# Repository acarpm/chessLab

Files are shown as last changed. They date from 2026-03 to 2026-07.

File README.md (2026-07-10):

# ChessLab — Documentation technique

Échiquier connecté détectant la position des pièces (capteurs à effet Hall) et affichant un retour visuel case par case (LEDs RGB adressables), pour visualiser une partie et aider à l'apprentissage du jeu.

## Architecture système

```
                        ESP32-C6
        WiFi 6 · BLE 5 · RISC-V 160 MHz · 512 KB SRAM
                            |
        +-------------------+-------------------+
        |                   |                   |
  Capteurs Hall         LEDs RGB           Alimentation
   (8x8 = 64)          (8x8 = 64)          Pack 18650
```

## Hardware

### Capteurs de position — SS49E

Capteur à effet Hall Analogique, suffisant pour détecter la présence ou l'absence d'une pièce sur une case. 

### LEDs — WS2812B (NeoPixel)

64 LEDs adressables individuellement, câblées en une seule chaîne série (une ligne de données, montage serpentin case par case). Alimentation 5 V, consommation crête d'environ 60 mA par LED.

### Multiplexage des capteurs Hall

64 capteurs analogiques dépassent le nombre de broches disponibles sur l'ESP32-C6. Solution retenue : multiplexeurs analogiques 74HC4051 (8 voies vers 1), soit 8 multiplexeurs pour 64 capteurs, ramenant le besoin à environ 11 broches ESP32.

### Alimentation — 18650

- 2 cellules 18650 montées en parallèle (~6000 mAh)
- Gestion de charge : IC TP4056
- Régulation :
  - 5 V / 3 A pour les LEDs WS2812B (convertisseur buck MP3608)
  - 3,3 V pour l'ESP32 et les capteurs Hall (LDO AMS1117-3.3)

## Circuit d'alimentation (mise sous tension)

Commutation assurée par un MOSFET P-Channel AO3401, piloté par le bouton d'alimentation et maintenu par l'ESP32 :

```
VBAT
 |
 R1 10k
 |
 +----------------------> Gate AO3401 (P-MOS)
 |                              |
 |        +---- R2 100k --------+
 |        |
 |     Source AO3401 = VBAT
 |        |
 |       Drain --------------------> VSYS
 |                                     |
BTN_PWR                          (MT3608 + AMS1117)
 |                                     |
 +---- vers Gate                 ESP32-C6
                                   |         |
                          GPIO_PWR_HOLD  GPIO_BTN_PWR
                          (maintien ON)  (lecture bouton)
```

**Séquence d'allumage**
1. Appui sur BTN_PWR
2. La gate du MOSFET passe à GND, le MOSFET conduit
3. VSYS s'active, l'ESP32 démarre
4. L'ESP32 maintient son GPIO à l'état bas pour garder le MOSFET conducteur
5. Le bouton peut être relâché, le système reste alimenté

**Extinction logicielle**
1. Inactivité détectée (par exemple 10 minutes sans coup joué)
2. Sauvegarde de l'état de la partie si nécessaire
3. Le GPIO passe à l'état haut, le MOSFET se bloque et coupe l'alimentation

**Extinction manuelle**
1. Appui long sur BTN_PWR (environ 3 secondes)
2. Détection par l'ESP32 via le GPIO de lecture du bouton
3. Même séquence que l'extinction logicielle

## Répartition des composants entre les deux cartes

| Carte principale | Carte d'alimentation |
|---|---|
| ESP32-C6 | TP4056 |
| Connecteur USB-C | DW01A + FS8205A |
| 64× WS2812B | Connecteur 18650 |
| 64× SS49E | MT3608 (5 V) |
| 8× 74HC4051 | AMS1117 (3,3 V) |
| 1× 74HC138 | Commutation MOSFET |
| BTN_BOOT + BTN_RESET | BTN_PWR + LED power |
| Connecteur JST vers carte d'alimentation | Connecteur JST vers carte principale |

Les deux cartes sont reliées par un connecteur JST 4 broches :

| Broche | Signal |
|---|---|
| 1 | VBAT (18650+) |
| 2 | GND |
| 3 | 5 V (sortie MT3608 vers carte principale) |
| 4 | 3,3 V (sortie AMS1117 vers carte principale) |

## Layout PCB

- Routage serpentin des WS2812B (entrée/sortie de données case par case)
- Matrices de capteurs Hall organisées en lignes/colonnes vers les multiplexeurs
- Épaisseur de PCB standard : 1,6 mm
- Couche diffusante imprimée en 3D au-dessus des LEDs

### Largeurs de piste

| Signal | Largeur |
|---|---|
| Données / GPIO | 0,25 mm |
| Alimentation 3,3 V | 0,5 mm |
| Alimentation 5 V (LEDs) | 1,0 mm |
| VBAT | 1,0 mm |
| VSYS | 1,0 mm |
| USB D+ / D- | 0,2 mm |

### Vias

| Type | Perçage | Pad |
|---|---|---|
| Standard | 0,4 mm | 0,8 mm |
| Puissance | 0,6 mm | 1,2 mm |

## Pinout ESP32-C6

| Broche | GPIO | Fonction |
|---|---|---|
| 13 | GPIO12 | USB D- |
| 14 | GPIO13 | USB D+ |
| 8 | GPIO0 | Mux — sélection canal S0 |
| 9 | GPIO1 | Mux — sélection canal S1 |
| 27 | GPIO2 | Mux — sélection canal S2 |
| 16 | GPIO18 | 74HC138 — sélection rangée A0 |
| 25 | GPIO16 | 74HC138 — sélection rangée A1 |
| 24 | GPIO17 | 74HC138 — sélection rangée A2 |
| 26 | GPIO3 | Lecture capteurs Hall (A_OUT) |
| 17 | GPIO19 | Données WS2812B (via résistance 33 Ω) |
| 18 | GPIO20 | VBAT |
| 15 | GPIO9 | Bouton BOOT |
| 19 | GPIO21 | Lecture bouton d'alimentation (BTN_PWR) |
| 20 | GPIO22 | Maintien alimentation (PWR_HOLD) |

## Fixation des pièces

Aimants cylindriques N52, Ø6×3 mm, insérés dans la base de chaque pièce et collés à l'époxy dans un logement imprimé en 3D. Ce choix permet une détection fiable par les capteurs Hall tout en restant invisible une fois la pièce posée.

## Boîtier

Hauteur totale estimée : 25 à 30 mm, dimensionnée pour loger la carte principale, la carte d'alimentation et les deux packs 18650.

## Firmware

Architecture logicielle sous FreeRTOS, organisée en tâches indépendantes :

| Tâche | Rôle |
|---|---|
| Hall Scanner | Scrutation des 64 capteurs (polling 50 ms) |
| LED Controller | Traduction de l'état de l'échiquier en animation LED |
| Chess Engine | Validation des positions et des coups légaux |
| BLE/WiFi | Communication avec l'application mobile ou l'interface web |
| Battery Monitor | Suivi de la tension batterie via diviseur de tension sur ADC |

**Bibliothèques envisagées**
- `FastLED` ou `Adafruit NeoPixel` pour le pilotage des WS2812B
- `Stockfish` (version allégée, via WASM) pour le moteur d'échecs
- Interface web servie depuis la mémoire flash (SPIFFS/LittleFS)

## Feuille de route

| Phase | Objectif |
|---|---|
| P1 | Prototype d'une case (1 LED + 1 capteur Hall + multiplexeur) sur breadboard |
| P2 | PCB de test 4×4 (KiCad) pour valider le multiplexage |
| P3 | PCB complet 8×8 et boîtier v1 |
| P4 | Firmware — moteur d'échecs et application |
| P5 | Impression 3D du boîtier final et des pièces modifiées |

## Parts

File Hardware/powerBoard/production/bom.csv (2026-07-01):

Designator | Footprint | Quantity | Value | LCSC Part #
BAT+1 | TestPoint_Pad_4.0x4.0mm | 1 | BAT+
BAT-1 | TestPoint_Pad_4.0x4.0mm | 1 | BAT-
BTN_PWR1, GND1, PWR_HOLD1, VBAT2, VSYS1 | TestPoint_Pad_4.0x4.0mm | 5 | ~
C1, C5 | 1206 | 2 | 100uF
C11, C12 | 0603 | 2 | 100µF
C3 | 0603 | 1 | 0.1uF
C6, C7 | 0603 | 2 | 10uF
D3 | D_SMA | 1 | SS34
D4, D5 | 0201 | 2 | LED
FB1 | CDRH4D28NP100NC | 1 | CDRH4D28NP-2R2NC
J4 | JST_B4B-XH-A_LF__SN_ | 1 | DATA
J5 | JST_B4B-XH-A_LF__SN_ | 1 | PWR
J6 | JST_B4B-XH-A_LF__SN_ | 1 | AUX
Q1 | SOP65P640X120-8N | 1 | FS8205A
Q2 | SOT-23 | 1 | AO3400A
R15 | 0603 | 1 | 100k
R16 | 0603 | 1 | 10k
R17, R18, R19 | 0603 | 3 | 1.1k
R3 | 0603 | 1 | 100
R4 | 0603 | 1 | 220k
R5 | 0603 | 1 | 33k
R7 | 0603 | 1 | 1k
TP10 | TestPoint_Pad_D2.0mm | 1 | 3V3
TP4 | TestPoint_Pad_D2.0mm | 1 | 5V
TP6 | TestPoint_Pad_D2.0mm | 1 | -BAT
U2 | SOT-223-3_TabPin2 | 1 | AMS1117-3.3
U3 | SOT-23-6 | 1 | DW01A
U4 | SOT-23-6 | 1 | MT3608
U5 | SOIC-8-1EP_3.9x4.9mm_P1.27mm_EP2.41x3.3mm_ThermalVias | 1 | TP4056

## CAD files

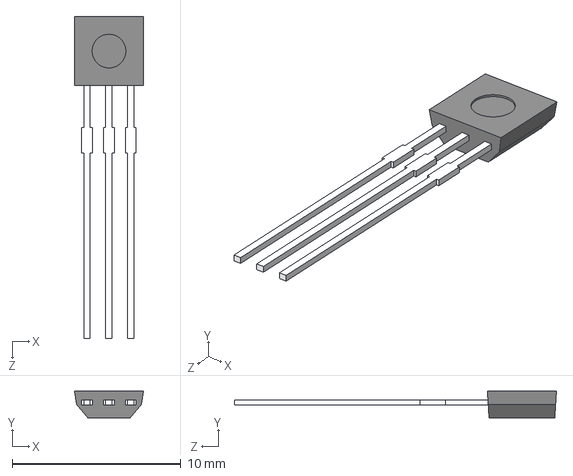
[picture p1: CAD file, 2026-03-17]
Hardware/kiCad_chessLab/3d-models/SS49E.stp
4.10 x 1.60 x 19.1 mm

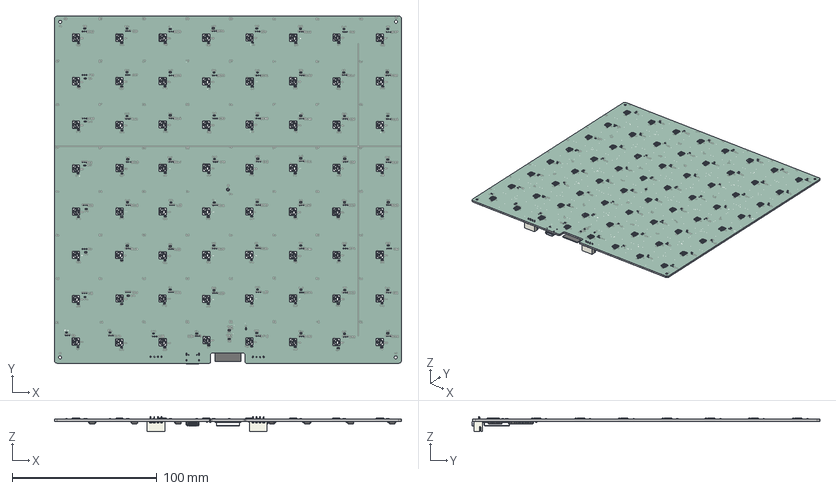
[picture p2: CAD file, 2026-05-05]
Hardware/kiCad_chessLab/kiCad_chessLab.step
240.0 x 240.4 x 10.4 mm
R_0603_1608Metric x 72
C_0603_1608Metric x 75
WS2812B--3DModel-STEP-55780 x 64
Body001 (Mirror #1) x 64
XY-plane x 96
X-axis x 96
TYPE-C-31-M-12
ESP32-C6-WROOM-1-N8
JST_XH_B4B-XH-A_1x04_P2.50mm_Vertical x 2
SOIC-16_3.9x9.9mm_P1.27mm
kiCad_chessLab_silkscreen x 2
kiCad_chessLab_soldermask x 2
kiCad_chessLab_PCB

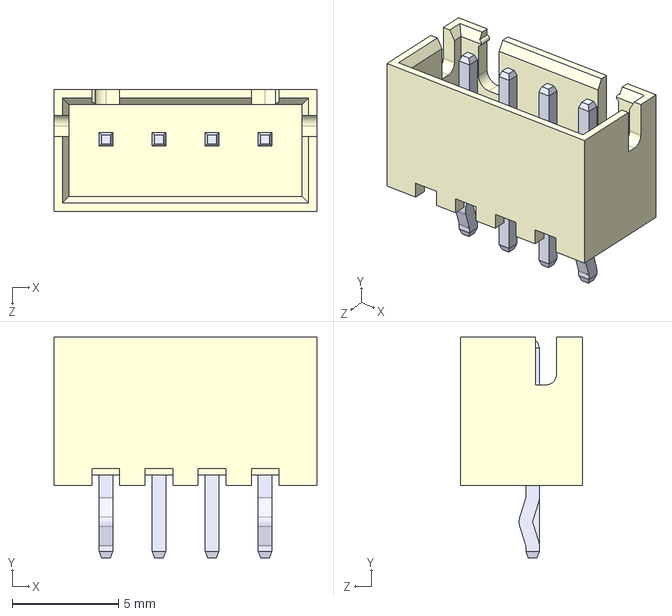
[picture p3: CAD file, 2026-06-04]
Hardware/powerBoard/_restore_backup_2026-05-26T12-30-36-239/B4B-XH-A_LF__SN_/B4B-XH-A_LF__SN_.step
12.4 x 10.4 x 5.75 mm

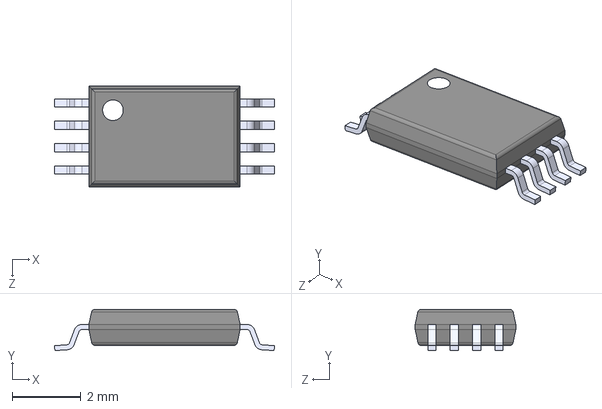
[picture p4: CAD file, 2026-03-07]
Hardware/powerBoard/_restore_backup_2026-05-26T12-30-36-239/FS8205A/FS8205A.step
6.40 x 1.20 x 2.93 mm

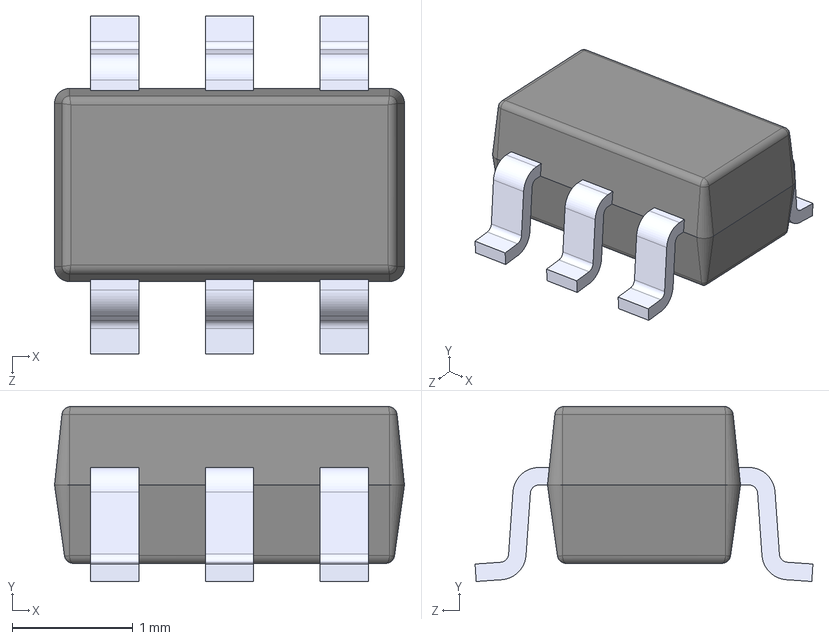
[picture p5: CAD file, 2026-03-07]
Hardware/kiCad_chessLab/3d-models/MT3608--3DModel-STEP-56544.STEP
2.90 x 1.45 x 2.80 mm

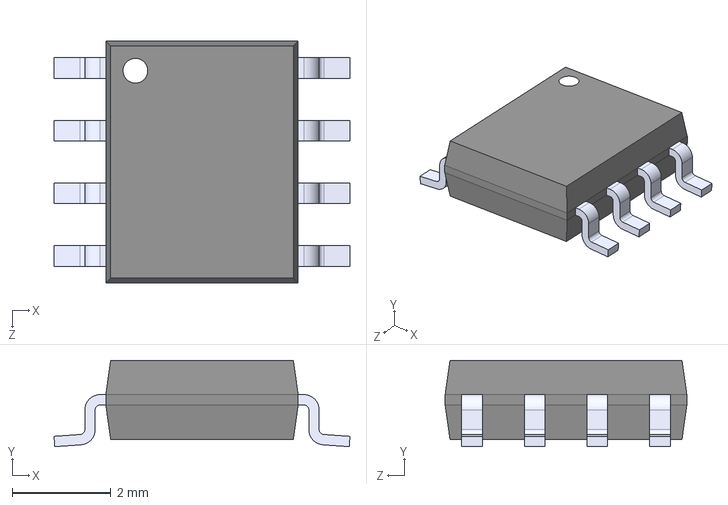
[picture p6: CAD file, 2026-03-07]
Hardware/kiCad_chessLab/3d-models/TP4056--3DModel-STEP-56544.STEP
6.00 x 1.75 x 4.90 mm

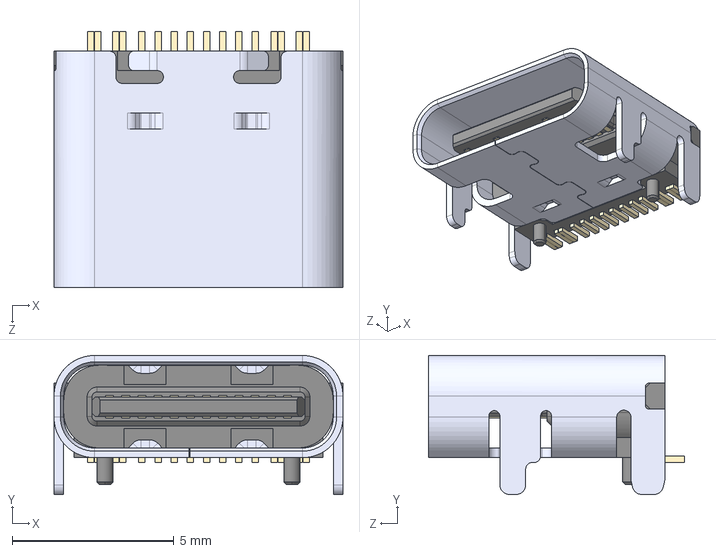
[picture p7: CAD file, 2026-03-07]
Hardware/kiCad_chessLab/3d-models/TYPE-C-31-M-12--3DModel-STEP-56544.STEP
8.94 x 4.30 x 7.90 mm

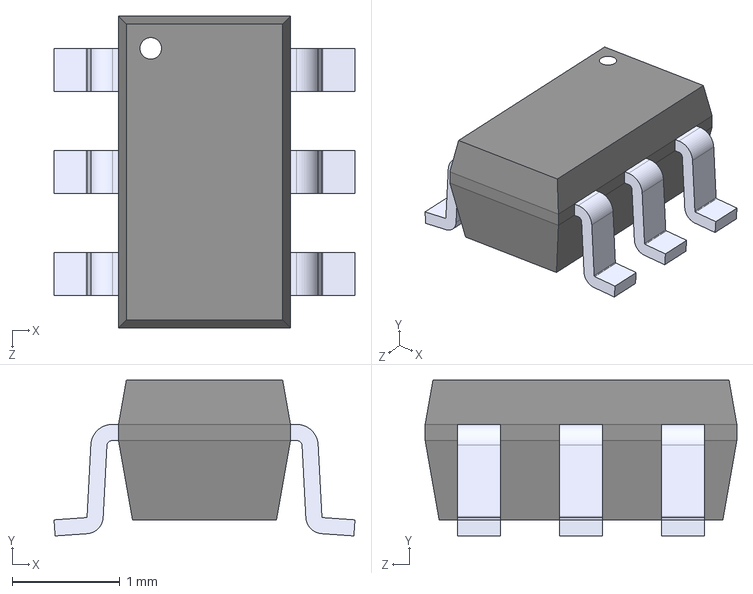
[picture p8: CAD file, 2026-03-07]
Hardware/kiCad_chessLab/3d-models/DW01A--3DModel-STEP-56544.STEP
2.80 x 1.45 x 2.90 mm

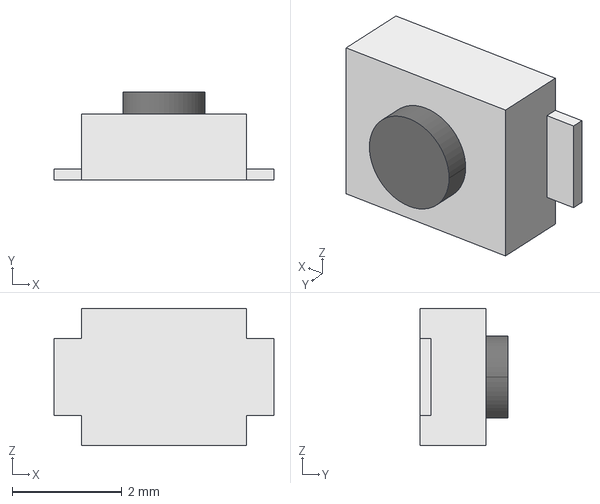
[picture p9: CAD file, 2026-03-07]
Hardware/kiCad_chessLab/3d-models/b3u-1000p.stp
4.00 x 1.60 x 2.50 mm

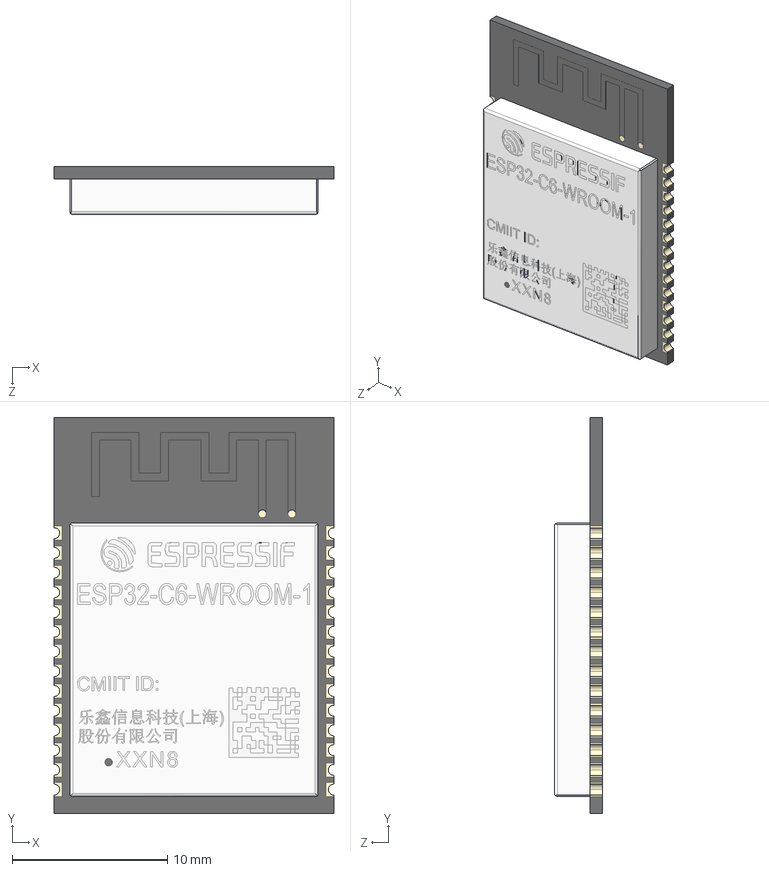
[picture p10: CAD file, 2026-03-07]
Hardware/kiCad_chessLab/3d-models/ESP32-C6-WROOM-1-N8.stp
18.0 x 25.5 x 3.11 mm

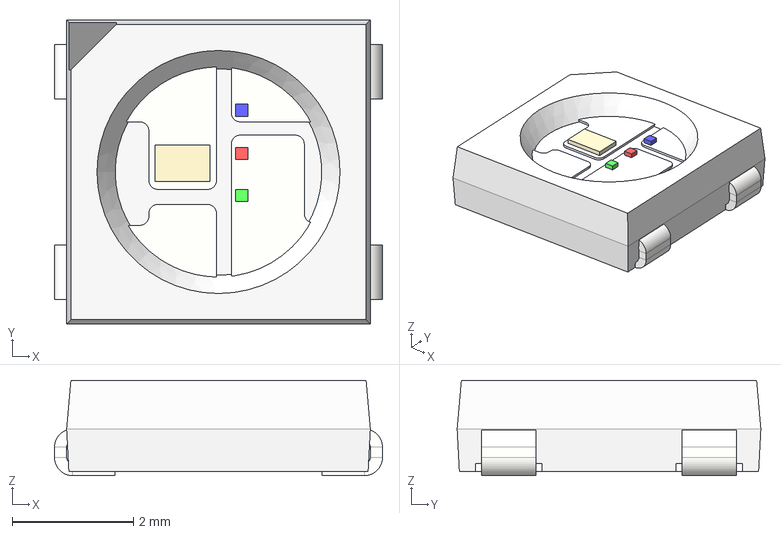
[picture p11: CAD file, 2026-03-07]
Hardware/kiCad_chessLab/3d-models/WS2812B--3DModel-STEP-55780.STEP
5.40 x 5.00 x 1.57 mm

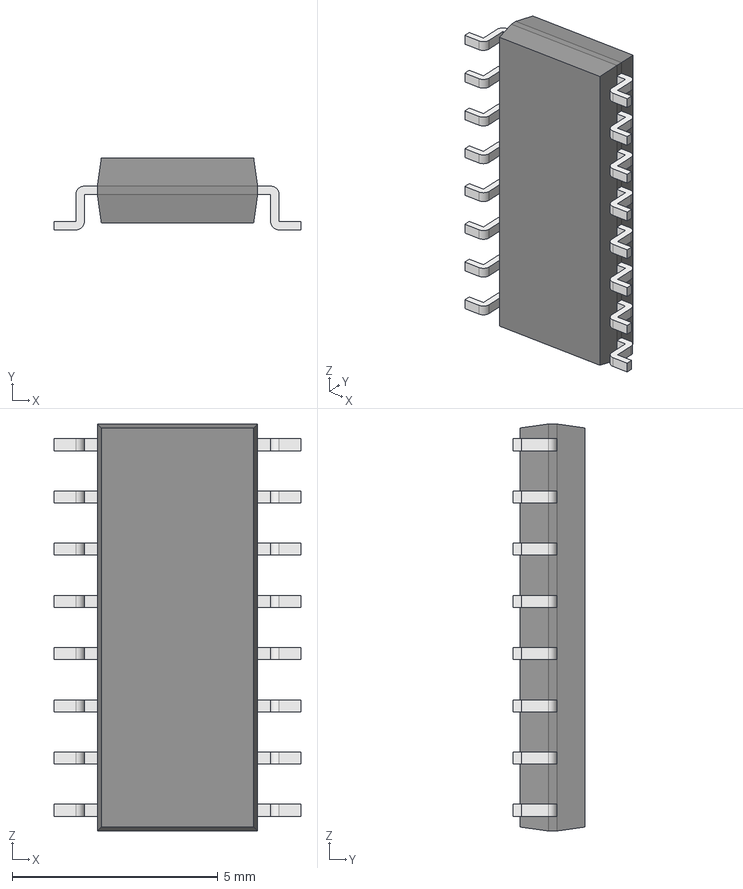
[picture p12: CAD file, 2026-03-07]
Hardware/kiCad_chessLab/3d-models/74HC4051D,653.STEP
6.00 x 1.75 x 9.90 mm
Body001 (Mirror #1) x 8
XY-plane x 12
X-axis x 12

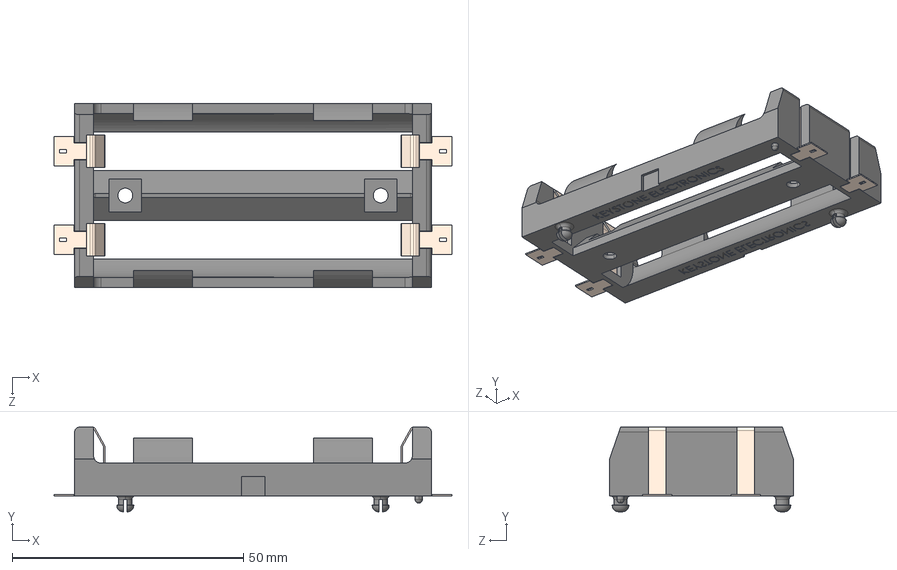
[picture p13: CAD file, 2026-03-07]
Hardware/kiCad_chessLab/3d-models/x218650.stp
86.0 x 18.3 x 39.8 mm

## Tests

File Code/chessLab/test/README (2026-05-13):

Plan : Réorganisation du firmware ChessLab en modules
Context
Le code fonctionne (Hall + LEDs OK) mais tout est dans un seul src/main.cpp de 149 lignes. Avant d'ajouter la logique de jeu et l'interface web, il faut séparer les responsabilités pour que chaque ajout futur soit isolé et testable. La vision finale : suivi du jeu en temps réel sur mobile/PC via WiFi AP.

Structure cible
include/
  board_config.h        ← toutes les constantes et pins (#define)
  hal_sensors.h         ← HAL : contrôle mux + lecture ADC brute
  hall_sensor.h         ← logique capteur : calibration, scan, deviations
  led_matrix.h          ← contrôle LEDs : NeoPixel, rendu, peak detection
  chess_game.h          ← [squelette] état du jeu, pièces, coups
  web_interface.h       ← [squelette] WiFi AP + WebSocket

src/
  main.cpp              ← uniquement setup() et loop()
  hal_sensors.cpp
  hall_sensor.cpp
  led_matrix.cpp
  chess_game.cpp
  web_interface.cpp
Détail des modules
include/board_config.h
Unique source de vérité pour toutes les constantes :

// Pins
LED_PIN=19, HALL_DOUT=3
DEC_A0=18, DEC_A1=16, DEC_A2=17
SEL_S0=0, SEL_S1=1, SEL_S2=2
// Dimensions
NUM_LEDS=64, BOARD_SIZE=8
// Tuning
BRIGHTNESS=15, HALL_RANGE=500, HALL_DEAD_ZONE=40, THRESHOLD=75, COL_OFFSET=0
// Réservé futur
FADE_DECAY=0.97f
hal_sensors.h/.cpp — HAL capteurs
Responsabilité : piloter les multiplexeurs et lire l'ADC. Pas de logique de jeu.

void sensors_init();
void sensors_select_row(int row);   // DEC_A0/A1/A2
void sensors_select_col(int col);   // SEL_S0/S1/S2
int  sensors_read_raw(int row, int col);  // moyenne 8 lectures ADC
write_addr() devient static interne (préservé mais non exposé).

hall_sensor.h/.cpp — Logique capteur Hall
Responsabilité : calibration et calcul des déviations. Dépend de hal_sensors.

void hall_calibrate();                    // lit baseline[8][8] une fois
void hall_scan(int dev[8][8]);            // abs(raw - baseline), applique DEAD_ZONE
void hall_dump_grid();                    // debug série 8x8
int  hall_get_baseline(int row, int col); // accesseur pour les tests
led_matrix.h/.cpp — Contrôle LEDs
Responsabilité : objet NeoPixel, indexation, rendu. Dépend de board_config.h seulement.

void     leds_init();
void     leds_update(int dev[8][8]);              // peak detection + brightness mapping + show()
void     leds_set_pixel(int row, int col, uint32_t color);
void     leds_clear();
void     leds_show();
int      leds_xy_to_index(int row, int col);      // linéaire (production)
int      leds_xy_to_index_serpentine(int row, int col); // préservé, utilisé dans test_led.cpp
fade[] et FADE_DECAY préservés en dead code commenté dans le .cpp.

chess_game.h/.cpp — [Squelette] Logique de jeu
Responsabilité future : détection des pièces, validation de coups, état de la partie.

void   game_init();
void   game_update(int dev[8][8]);    // met à jour l'état à partir des déviations
// À compléter : game_get_state(), game_get_moves(), etc.
web_interface.h/.cpp — [Squelette] Interface web
Responsabilité future : WiFi AP + WebSocket pour suivi en temps réel sur mobile/PC.

void web_init();       // démarre WiFi AP + serveur WebSocket
void web_update();     // à appeler dans loop(), gère les clients connectés
void web_broadcast_state(int dev[8][8]); // envoie l'état du plateau en JSON
Squelette vide pour l'instant — les fonctions existent mais ne font rien.

src/main.cpp final
#include "board_config.h"
#include "hal_sensors.h"
#include "hall_sensor.h"
#include "led_matrix.h"
#include "chess_game.h"
#include "web_interface.h"

void setup() {
    Serial.begin(115200);
    sensors_init();
    leds_init();
    hall_calibrate();
    game_init();
    web_init();
}

void loop() {
    static int dev[8][8];
    hall_scan(dev);
    leds_update(dev);
    game_update(dev);
    web_update();
}
Dépendances (aucune circulaire)
board_config.h
    ↓
hal_sensors ──→ hall_sensor
                    ↓
led_matrix ←── main.cpp ──→ chess_game
                    ↓
             web_interface

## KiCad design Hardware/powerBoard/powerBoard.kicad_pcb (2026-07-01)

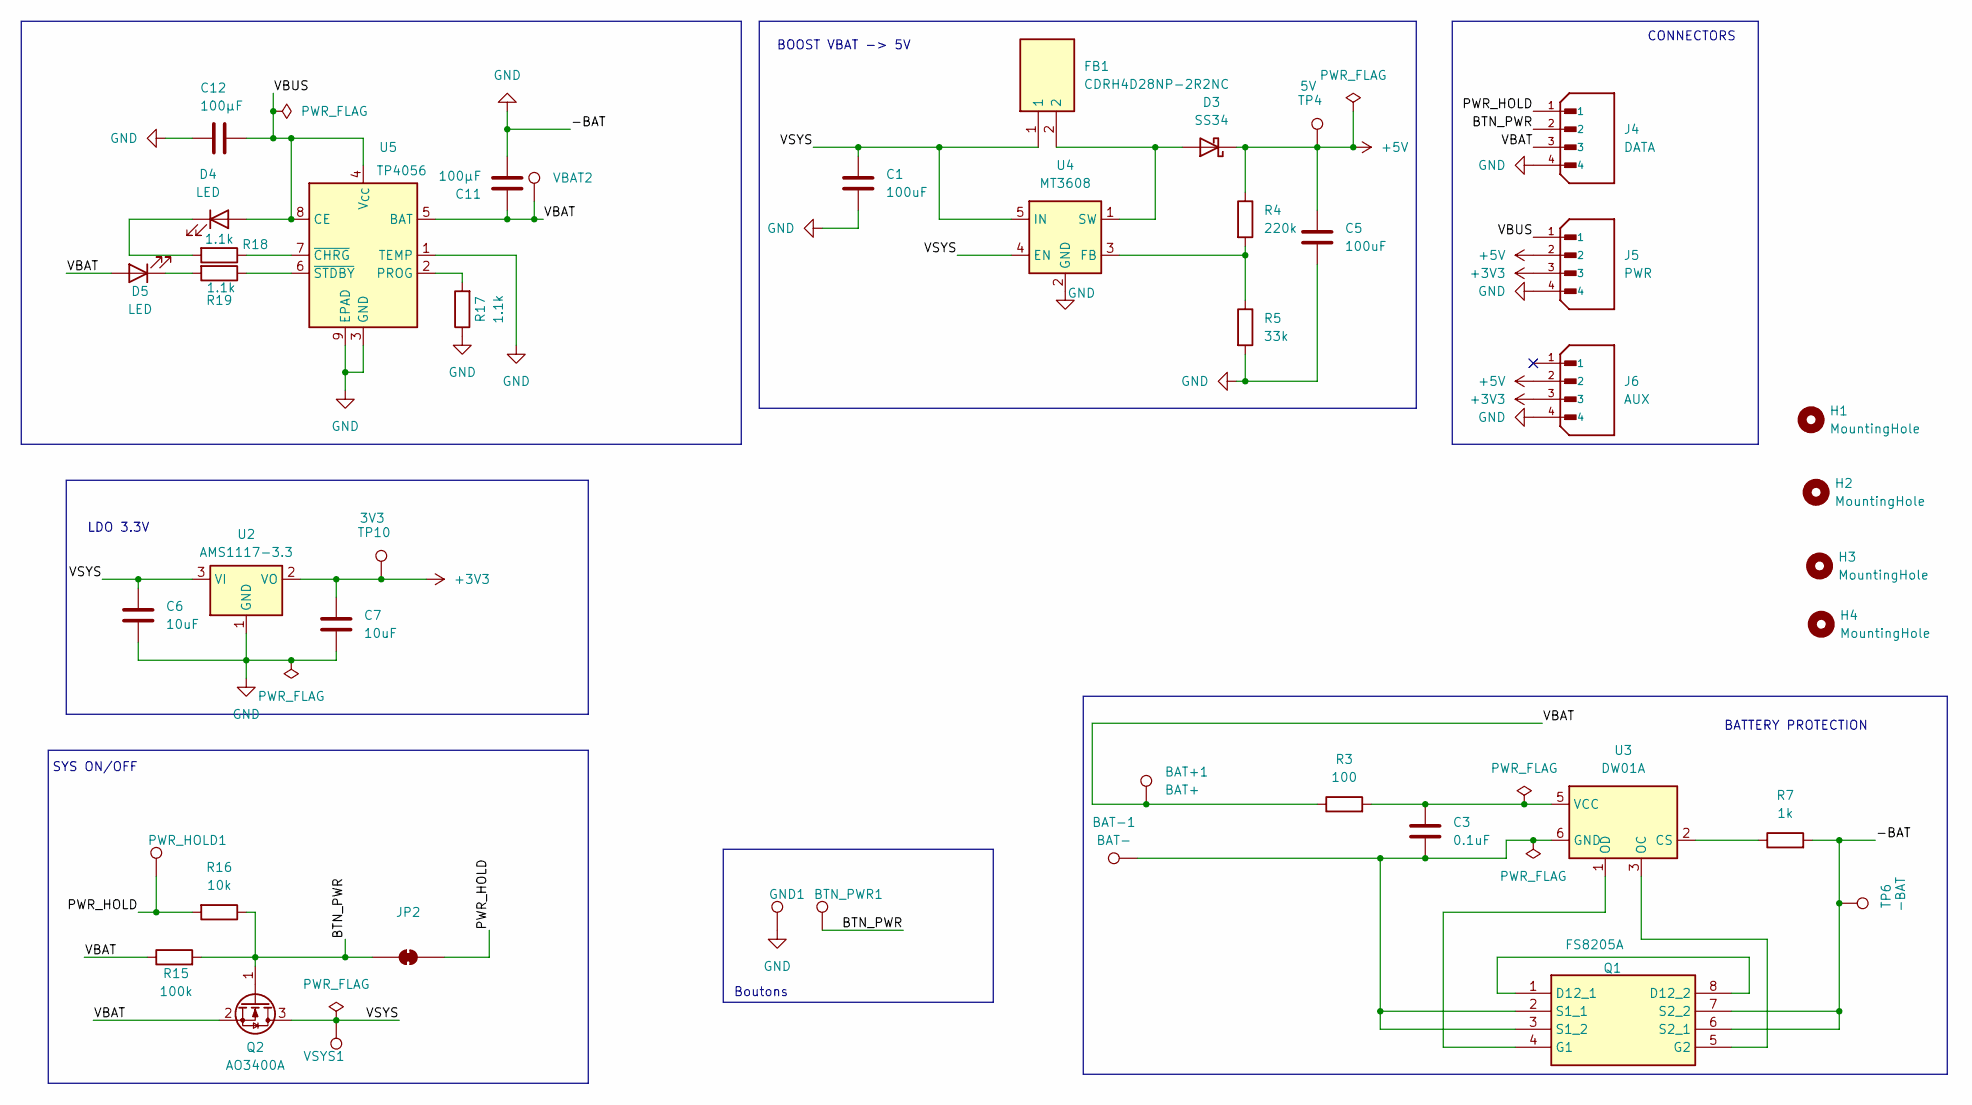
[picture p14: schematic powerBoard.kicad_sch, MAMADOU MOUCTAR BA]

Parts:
BAT+1: BAT+; TestPoint_Pad_4.0x4.0mm
BAT-1: BAT-; TestPoint_Pad_4.0x4.0mm
BTN_PWR1: TestPoint_Pad_4.0x4.0mm
C1, C5: 100uF; C_1206_3216Metric_Pad1.33x1.80mm_HandSolder
C3: 0.1uF; C_0603_1608Metric_Pad1.08x0.95mm_HandSolder
C6, C7: 10uF; C_0603_1608Metric_Pad1.08x0.95mm_HandSolder
C11, C12: 100µF; C_0603_1608Metric_Pad1.08x0.95mm_HandSolder
D3: SS34; D_SMA
D4, D5: LED; LED_0201_0603Metric
FB1: CDRH4D28NP-2R2NC; CDRH4D28NP100NC; Mouser Part Number 851-CDRH4D28NP-2R2NC
GND1: TestPoint_Pad_4.0x4.0mm
H1, H2, H3, H4: MountingHole; MountingHole_2.7mm_M2.5
J4: DATA; JST_B4B-XH-A_LF__SN_; PARTREV 7/4/21
J5: PWR; JST_B4B-XH-A_LF__SN_; PARTREV 7/4/21
J6: AUX; JST_B4B-XH-A_LF__SN_; PARTREV 7/4/21
JP2: SolderJumper_2_Bridged; SolderJumper-2_P1.3mm_Bridged2Bar_RoundedPad1.0x1.5mm
PWR_HOLD1: TestPoint_Pad_4.0x4.0mm
Q1: FS8205A; SOP65P640X120-8N; Manufacturer_Part_Number FS8205A
Q2: AO3400A; SOT-23
R3: 100; R_0603_1608Metric_Pad0.98x0.95mm_HandSolder
R4: 220k; R_0603_1608Metric_Pad0.98x0.95mm_HandSolder
R5: 33k; R_0603_1608Metric_Pad0.98x0.95mm_HandSolder
R7: 1k; R_0603_1608Metric_Pad0.98x0.95mm_HandSolder
R15: 100k; R_0603_1608Metric_Pad0.98x0.95mm_HandSolder
R16: 10k; R_0603_1608Metric_Pad0.98x0.95mm_HandSolder
R17, R18, R19: 1.1k; R_0603_1608Metric_Pad0.98x0.95mm_HandSolder
TP4: 5V; TestPoint_Pad_D2.0mm
TP6: -BAT; TestPoint_Pad_D2.0mm
TP10: 3V3; TestPoint_Pad_D2.0mm
U2: AMS1117-3.3; SOT-223-3_TabPin2
U3: DW01A; SOT-23-6
U4: MT3608; SOT-23-6
U5: TP4056; SOIC-8-1EP_3.9x4.9mm_P1.27mm_EP2.41x3.3mm_ThermalVias
VBAT2: TestPoint_Pad_4.0x4.0mm
VSYS1: TestPoint_Pad_4.0x4.0mm

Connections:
+3V3: C7.1, J5.3, J6.3, TP10.1 (1_1), U2.2 (VO)
+5V: C5.1, D3.1 (K), J5.2, J6.2, R4.1, TP4.1 (1_1)
/BTN_PWR: BTN_PWR1.1 (1_1), J4.2, JP2.1 (A), Q2.1 (G), R15.2, R16.1
/PWR_HOLD: J4.1, JP2.2 (B), PWR_HOLD1.1 (1_1), R16.2
/VBAT: BAT+1.1 (1_1), C11.1, D5.2 (A), J4.3, Q2.2 (S), R3.1, R15.1, U5.5 (BAT), VBAT2.1 (1_1)
/VBUS: C12.1, D4.2 (A), J5.1, U5.4 (V_{CC}), U5.8 (CE)
/VSYS: C1.1, C6.1, FB1.1, Q2.3 (D), U2.3 (VI), U4.4 (EN), U4.5 (IN), VSYS1.1 (1_1)
GND: C1.2, C5.2, C6.2, C7.2, C11.2, C12.2, GND1.1 (1_1), J4.4, J5.4, J6.4, Q1.6 (S2_1), Q1.7 (S2_2), R5.2, R7.2, R17.1, TP6.1 (1_1), U2.1 (GND), U4.2 (GND), U5.1 (TEMP), U5.3 (GND), U5.9 (EPAD)
unnamed: D3.2 (A), FB1.2, U4.1 (SW)
unnamed: D4.1 (K), R18.2
unnamed: D5.1 (K), R19.2
unnamed: Q1.1 (D12_1), Q1.8 (D12_2)
unnamed: Q1.4 (G1), U3.1 (OD)
unnamed: Q1.5 (G2), U3.3 (OC)
unnamed: BAT-1.1 (1_1), C3.2, Q1.2 (S1_1), Q1.3 (S1_2), U3.6 (GND)
unnamed: R7.1, U3.2 (CS)
unnamed: C3.1, R3.2, U3.5 (VCC)
unnamed: R4.2, R5.1, U4.3 (FB)
unnamed: R17.2, U5.2 (PROG)
unnamed: R18.1, U5.7 (~CHRG)
unnamed: R19.1, U5.6 (~STDBY)

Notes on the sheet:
BOOST VBAT -> 5V
CONNECTORS
BATTERY PROTECTION
LDO 3.3V
SYS ON/OFF
Boutons

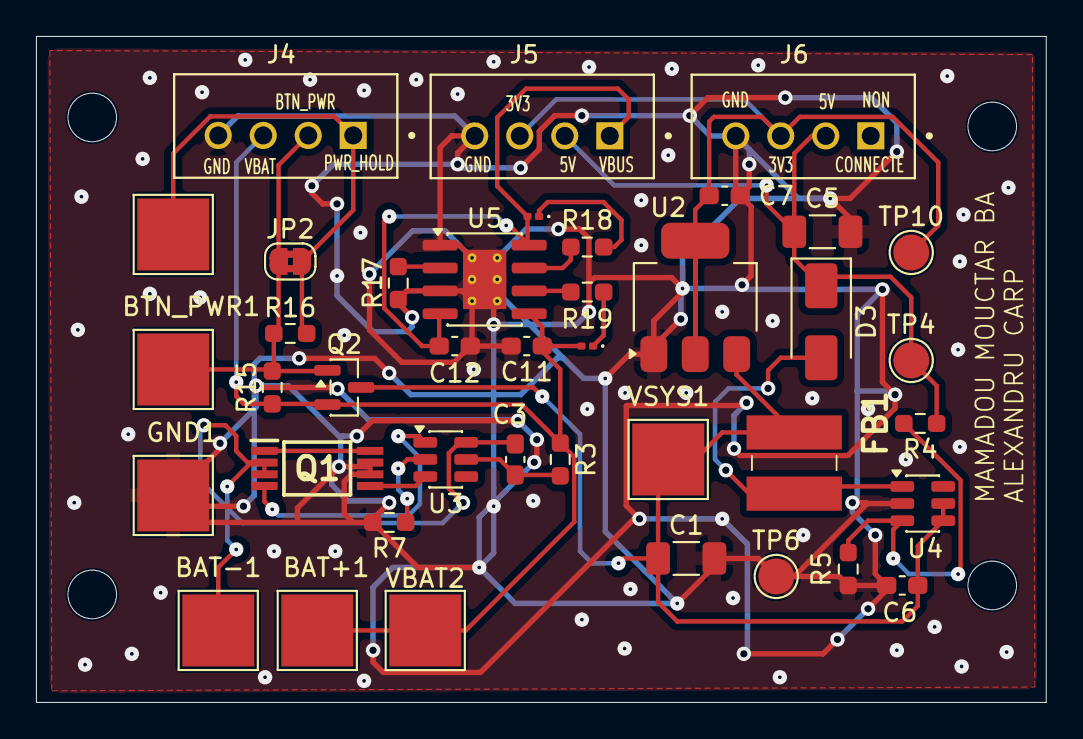
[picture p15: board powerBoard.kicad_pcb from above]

Board: 2 copper layers, 56.1 x 37.0 mm, 44 parts (0 on the bottom side), 21 nets.

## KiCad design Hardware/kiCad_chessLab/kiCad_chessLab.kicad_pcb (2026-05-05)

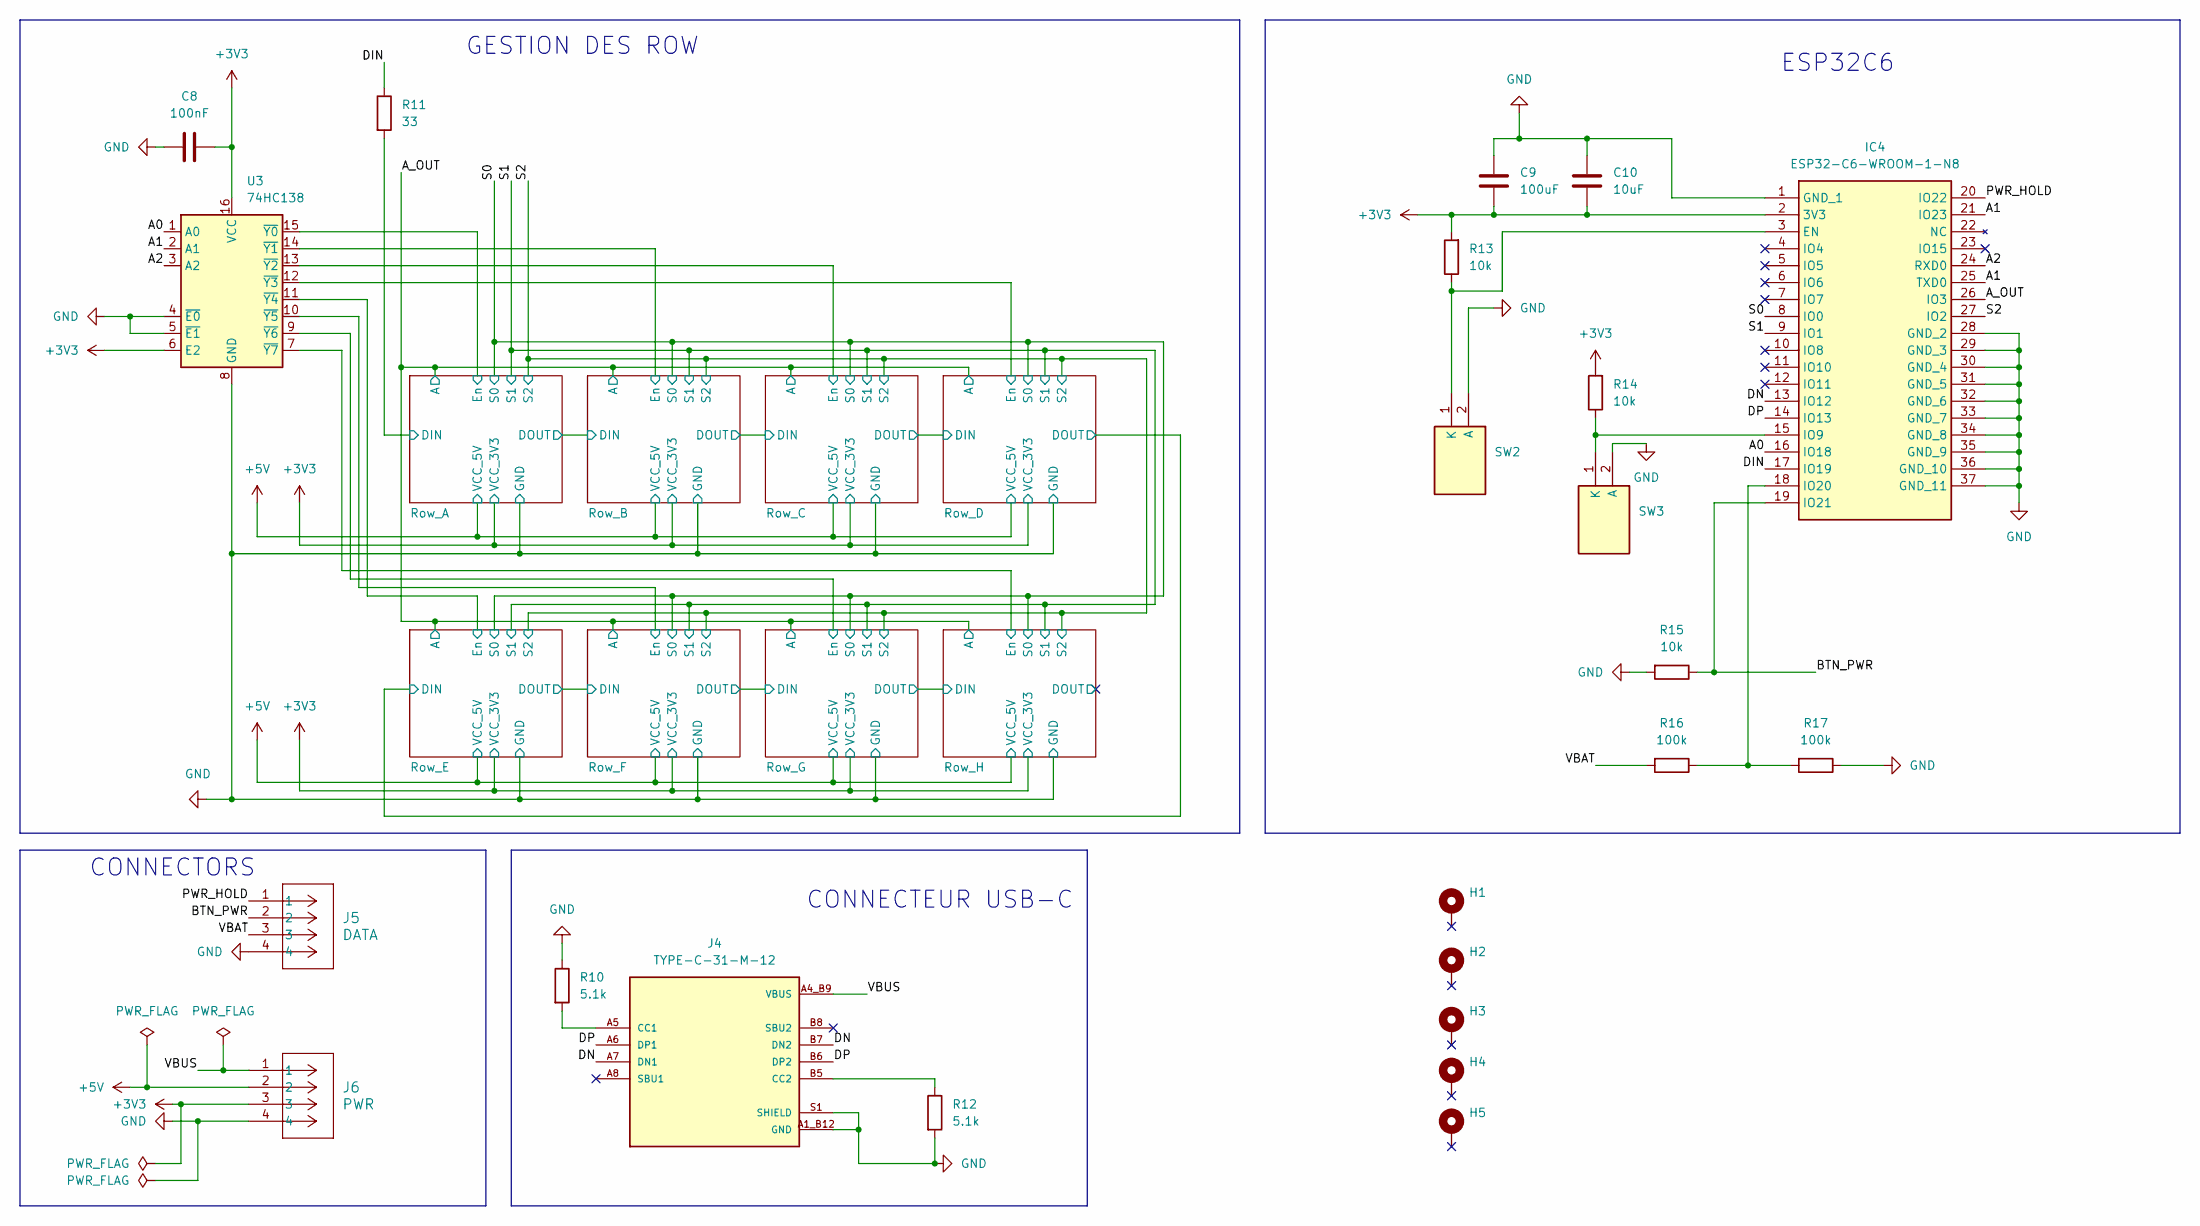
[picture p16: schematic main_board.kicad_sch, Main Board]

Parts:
C8: 100nF; C_0603_1608Metric_Pad1.08x0.95mm_HandSolder
C9: 100uF; C_0603_1608Metric_Pad1.08x0.95mm_HandSolder
C10: 10uF; C_0603_1608Metric_Pad1.08x0.95mm_HandSolder
H1, H2, H3, H4, H5: MountingHole_Pad; MountingHole_2.2mm_M2_DIN965_Pad
IC4: ESP32-C6-WROOM-1-N8; ESP32C6WROOM1N8; Mouser Part Number 356-ESP32C6WROOM1N8
J4: TYPE-C-31-M-12; HRO_TYPE-C-31-M-12; PARTREV 2020.12.08
J5: DATA; JST_XH_B4B-XH-A_1x04_P2.50mm_Vertical
J6: PWR; JST_XH_B4B-XH-A_1x04_P2.50mm_Vertical
R10, R12: 5.1k; R_0603_1608Metric_Pad0.98x0.95mm_HandSolder
R11: 33; R_0603_1608Metric_Pad0.98x0.95mm_HandSolder
R13, R14, R15: 10k; R_0603_1608Metric_Pad0.98x0.95mm_HandSolder
R16, R17: 100k; R_0603_1608Metric_Pad0.98x0.95mm_HandSolder
SW2: RST; B3U-1000P; Mouser Part Number 653-B3U-1000P
SW3: BOOT; B3U-1000P; Mouser Part Number 653-B3U-1000P
U3: 74HC138; SOIC-16_3.9x9.9mm_P1.27mm

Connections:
+3V3: C8.2, C9.2, C10.2, IC4.2 (3V3), J6.3, R13.2, R14.2, U3.6 (E2), U3.16 (VCC); also elsewhere on the board
+5V: J6.2; also elsewhere on the board
/Main Board/A0: IC4.16 (IO18), U3.1 (A0)
/Main Board/A1: IC4.21 (IO23), IC4.25 (TXD0), U3.2 (A1)
/Main Board/A2: IC4.24 (RXD0), U3.3 (A2)
/Main Board/A_OUT: IC4.26 (IO3); also elsewhere on the board
/Main Board/BTN_PWR: IC4.19 (IO21), J5.2, R15.1
/Main Board/DIN: IC4.17 (IO19), R11.1
/Main Board/DN: IC4.13 (IO12), J4.A7 (DN1), J4.B7 (DN2)
/Main Board/DP: IC4.14 (IO13), J4.A6 (DP1), J4.B6 (DP2)
/Main Board/PWR_HOLD: IC4.20 (IO22), J5.1
/Main Board/Row_A/DIN: R11.2; also elsewhere on the board
/Main Board/Row_A/En: U3.15 (~Y0); also elsewhere on the board
/Main Board/Row_B/En: U3.14 (~Y1); also elsewhere on the board
/Main Board/Row_C/En: U3.13 (~Y2); also elsewhere on the board
/Main Board/Row_D/En: U3.12 (~Y3); also elsewhere on the board
/Main Board/Row_E/En: U3.11 (~Y4); also elsewhere on the board
/Main Board/Row_F/En: U3.10 (~Y5); also elsewhere on the board
/Main Board/Row_G/En: U3.9 (~Y6); also elsewhere on the board
/Main Board/Row_H/En: U3.7 (~Y7); also elsewhere on the board
/Main Board/S0: IC4.8 (IO0); also elsewhere on the board
/Main Board/S1: IC4.9 (IO1); also elsewhere on the board
/Main Board/S2: IC4.27 (IO2); also elsewhere on the board
/Main Board/VBAT: J5.3, R16.2
GND: C8.1, C9.1, C10.1, IC4.1 (GND_1), IC4.28 (GND_2), IC4.29 (GND_3), IC4.30 (GND_4), IC4.31 (GND_5), IC4.32 (GND_6), IC4.33 (GND_7), IC4.34 (GND_8), IC4.35 (GND_9), IC4.36 (GND_10), IC4.37 (GND_11), J4.A1_B12 (GND), J4.B1_A12 (GND), J4.S1 (SHIELD), J4.S2 (SHIELD), J4.S3 (SHIELD), J4.S4 (SHIELD), J5.4, J6.4, R10.1, R12.2, R15.2, R17.1, SW2.2 (A), SW3.2 (A), U3.4 (~E0), U3.5 (~E1), U3.8 (GND); also elsewhere on the board
unnamed: IC4.3 (EN), R13.1, SW2.1 (K)
unnamed: IC4.15 (IO9), R14.1, SW3.1 (K)
unnamed: IC4.18 (IO20), R16.1, R17.2
unnamed: J4.A5 (CC1), R10.2
unnamed: J4.B5 (CC2), R12.1
VBUS: J4.A4_B9 (VBUS), J4.B4_A9 (VBUS), J6.1

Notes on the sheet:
GESTION DES ROW
ESP32C6
CONNECTORS
CONNECTEUR USB-C

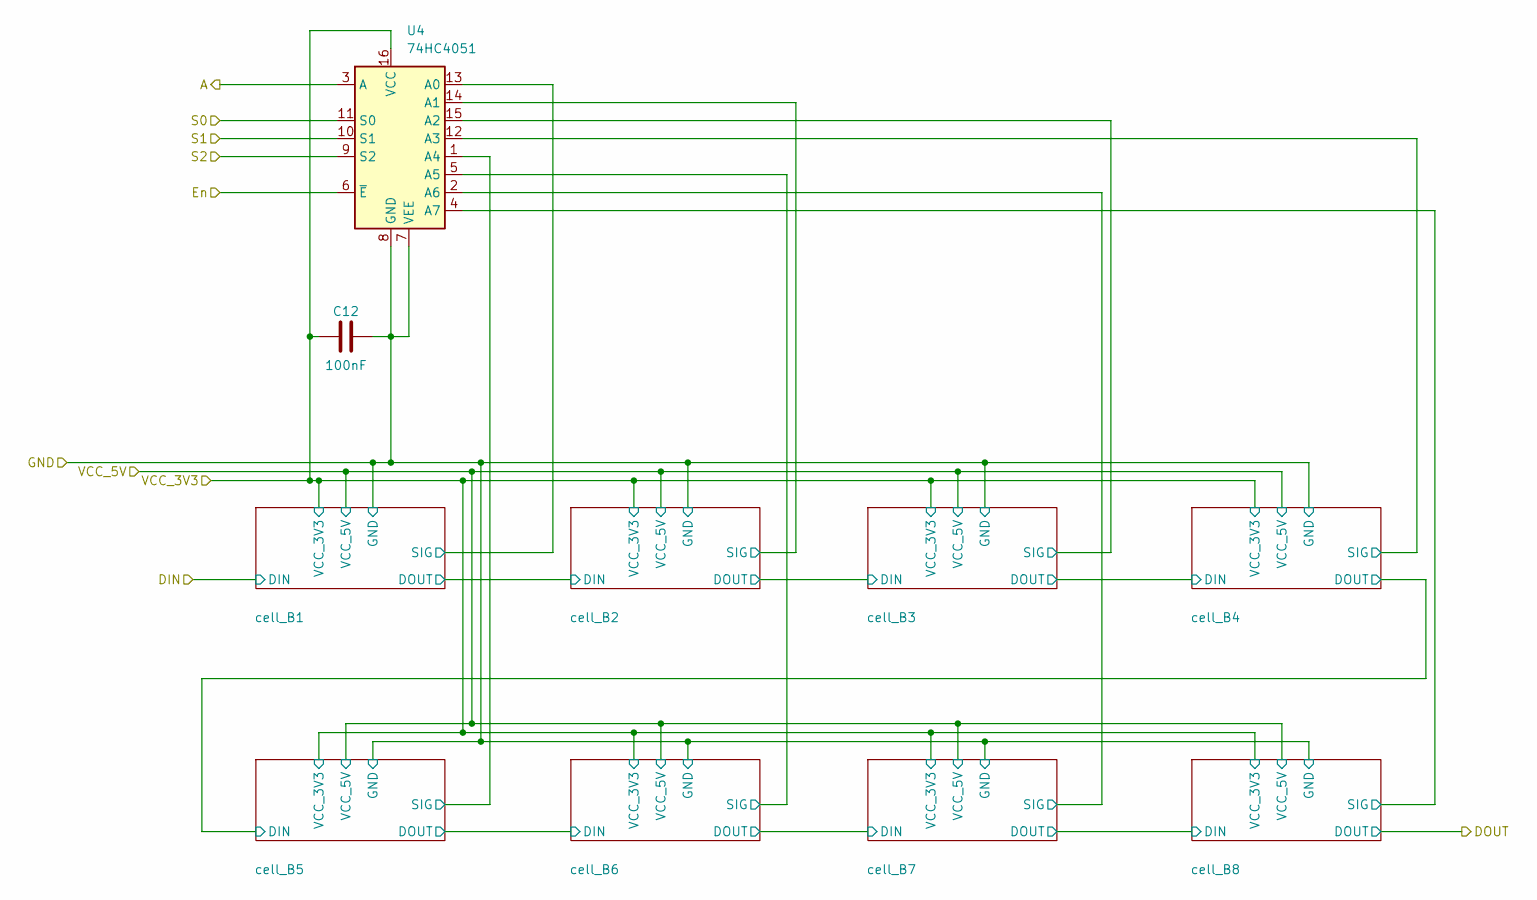
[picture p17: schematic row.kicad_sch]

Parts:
C12: 100nF; C_0603_1608Metric_Pad1.08x0.95mm_HandSolder
U4: 74HC4051; 74HC4051D653

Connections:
+3V3: C12.1, U4.16 (VCC); also elsewhere on the board
/Main Board/A_OUT: U4.3 (A); also elsewhere on the board
/Main Board/Row_A/En: U4.6 (~E); also elsewhere on the board
/Main Board/Row_A/cell_B1/SIG: U4.13 (A0); also elsewhere on the board
/Main Board/Row_A/cell_B2/SIG: U4.14 (A1); also elsewhere on the board
/Main Board/Row_A/cell_B3/SIG: U4.15 (A2); also elsewhere on the board
/Main Board/Row_A/cell_B4/SIG: U4.12 (A3); also elsewhere on the board
/Main Board/Row_A/cell_B5/SIG: U4.1 (A4); also elsewhere on the board
/Main Board/Row_A/cell_B6/SIG: U4.5 (A5); also elsewhere on the board
/Main Board/Row_A/cell_B7/SIG: U4.2 (A6); also elsewhere on the board
/Main Board/Row_A/cell_B8/SIG: U4.4 (A7); also elsewhere on the board
/Main Board/S0: U4.11 (S0); also elsewhere on the board
/Main Board/S1: U4.10 (S1); also elsewhere on the board
/Main Board/S2: U4.9 (S2); also elsewhere on the board
GND: C12.2, U4.7 (VEE), U4.8 (GND); also elsewhere on the board

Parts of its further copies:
C20, C29, C38, C47, C56, C65, C74: 100nF; C_0603_1608Metric_Pad1.08x0.95mm_HandSolder
U5, U6, U7, U8, U9, U10, U11: 74HC4051; 74HC4051D653

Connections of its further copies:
+3V3: C20.1, C29.1, C38.1, C47.1, C56.1, C65.1, C74.1, U5.16 (VCC), U6.16 (VCC), U7.16 (VCC), U8.16 (VCC), U9.16 (VCC), U10.16 (VCC), U11.16 (VCC); also elsewhere on the board
/Main Board/A_OUT: U5.3 (A), U6.3 (A), U7.3 (A), U8.3 (A), U9.3 (A), U10.3 (A), U11.3 (A); also elsewhere on the board
/Main Board/Row_B/En: U5.6 (~E); also elsewhere on the board
/Main Board/Row_B/cell_B1/SIG: U5.13 (A0); also elsewhere on the board
/Main Board/Row_B/cell_B2/SIG: U5.14 (A1); also elsewhere on the board
/Main Board/Row_B/cell_B3/SIG: U5.15 (A2); also elsewhere on the board
/Main Board/Row_B/cell_B4/SIG: U5.12 (A3); also elsewhere on the board
/Main Board/Row_B/cell_B5/SIG: U5.1 (A4); also elsewhere on the board
/Main Board/Row_B/cell_B6/SIG: U5.5 (A5); also elsewhere on the board
/Main Board/Row_B/cell_B7/SIG: U5.2 (A6); also elsewhere on the board
/Main Board/Row_B/cell_B8/SIG: U5.4 (A7); also elsewhere on the board
/Main Board/Row_C/En: U6.6 (~E); also elsewhere on the board
/Main Board/Row_C/cell_B1/SIG: U6.13 (A0); also elsewhere on the board
/Main Board/Row_C/cell_B2/SIG: U6.14 (A1); also elsewhere on the board
/Main Board/Row_C/cell_B3/SIG: U6.15 (A2); also elsewhere on the board
/Main Board/Row_C/cell_B4/SIG: U6.12 (A3); also elsewhere on the board
/Main Board/Row_C/cell_B5/SIG: U6.1 (A4); also elsewhere on the board
/Main Board/Row_C/cell_B6/SIG: U6.5 (A5); also elsewhere on the board
/Main Board/Row_C/cell_B7/SIG: U6.2 (A6); also elsewhere on the board
/Main Board/Row_C/cell_B8/SIG: U6.4 (A7); also elsewhere on the board
/Main Board/Row_D/En: U7.6 (~E); also elsewhere on the board
/Main Board/Row_D/cell_B1/SIG: U7.13 (A0); also elsewhere on the board
/Main Board/Row_D/cell_B2/SIG: U7.14 (A1); also elsewhere on the board
/Main Board/Row_D/cell_B3/SIG: U7.15 (A2); also elsewhere on the board
/Main Board/Row_D/cell_B4/SIG: U7.12 (A3); also elsewhere on the board
/Main Board/Row_D/cell_B5/SIG: U7.1 (A4); also elsewhere on the board
/Main Board/Row_D/cell_B6/SIG: U7.5 (A5); also elsewhere on the board
/Main Board/Row_D/cell_B7/SIG: U7.2 (A6); also elsewhere on the board
/Main Board/Row_D/cell_B8/SIG: U7.4 (A7); also elsewhere on the board
/Main Board/Row_E/En: U8.6 (~E); also elsewhere on the board
/Main Board/Row_E/cell_B1/SIG: U8.13 (A0); also elsewhere on the board
/Main Board/Row_E/cell_B2/SIG: U8.14 (A1); also elsewhere on the board
/Main Board/Row_E/cell_B3/SIG: U8.15 (A2); also elsewhere on the board
/Main Board/Row_E/cell_B4/SIG: U8.12 (A3); also elsewhere on the board
/Main Board/Row_E/cell_B5/SIG: U8.1 (A4); also elsewhere on the board
/Main Board/Row_E/cell_B6/SIG: U8.5 (A5); also elsewhere on the board
/Main Board/Row_E/cell_B7/SIG: U8.2 (A6); also elsewhere on the board
/Main Board/Row_E/cell_B8/SIG: U8.4 (A7); also elsewhere on the board
/Main Board/Row_F/En: U9.6 (~E); also elsewhere on the board
/Main Board/Row_F/cell_B1/SIG: U9.13 (A0); also elsewhere on the board
/Main Board/Row_F/cell_B2/SIG: U9.14 (A1); also elsewhere on the board
/Main Board/Row_F/cell_B3/SIG: U9.15 (A2); also elsewhere on the board
/Main Board/Row_F/cell_B4/SIG: U9.12 (A3); also elsewhere on the board
/Main Board/Row_F/cell_B5/SIG: U9.1 (A4); also elsewhere on the board
/Main Board/Row_F/cell_B6/SIG: U9.5 (A5); also elsewhere on the board
/Main Board/Row_F/cell_B7/SIG: U9.2 (A6); also elsewhere on the board
/Main Board/Row_F/cell_B8/SIG: U9.4 (A7); also elsewhere on the board
/Main Board/Row_G/En: U10.6 (~E); also elsewhere on the board
/Main Board/Row_G/cell_B1/SIG: U10.13 (A0); also elsewhere on the board
/Main Board/Row_G/cell_B2/SIG: U10.14 (A1); also elsewhere on the board
/Main Board/Row_G/cell_B3/SIG: U10.15 (A2); also elsewhere on the board
/Main Board/Row_G/cell_B4/SIG: U10.12 (A3); also elsewhere on the board
/Main Board/Row_G/cell_B5/SIG: U10.1 (A4); also elsewhere on the board
/Main Board/Row_G/cell_B6/SIG: U10.5 (A5); also elsewhere on the board
/Main Board/Row_G/cell_B7/SIG: U10.2 (A6); also elsewhere on the board
/Main Board/Row_G/cell_B8/SIG: U10.4 (A7); also elsewhere on the board
/Main Board/Row_H/En: U11.6 (~E); also elsewhere on the board
/Main Board/Row_H/cell_B1/SIG: U11.13 (A0); also elsewhere on the board
/Main Board/Row_H/cell_B2/SIG: U11.14 (A1); also elsewhere on the board
/Main Board/Row_H/cell_B3/SIG: U11.15 (A2); also elsewhere on the board
/Main Board/Row_H/cell_B4/SIG: U11.12 (A3); also elsewhere on the board
/Main Board/Row_H/cell_B5/SIG: U11.1 (A4); also elsewhere on the board
/Main Board/Row_H/cell_B6/SIG: U11.5 (A5); also elsewhere on the board
/Main Board/Row_H/cell_B7/SIG: U11.2 (A6); also elsewhere on the board
/Main Board/Row_H/cell_B8/SIG: U11.4 (A7); also elsewhere on the board
/Main Board/S0: U5.11 (S0), U6.11 (S0), U7.11 (S0), U8.11 (S0), U9.11 (S0), U10.11 (S0), U11.11 (S0); also elsewhere on the board
/Main Board/S1: U5.10 (S1), U6.10 (S1), U7.10 (S1), U8.10 (S1), U9.10 (S1), U10.10 (S1), U11.10 (S1); also elsewhere on the board
/Main Board/S2: U5.9 (S2), U6.9 (S2), U7.9 (S2), U8.9 (S2), U9.9 (S2), U10.9 (S2), U11.9 (S2); also elsewhere on the board
GND: C20.2, C29.2, C38.2, C47.2, C56.2, C65.2, C74.2, U5.7 (VEE), U5.8 (GND), U6.7 (VEE), U6.8 (GND), U7.7 (VEE), U7.8 (GND), U8.7 (VEE), U8.8 (GND), U9.7 (VEE), U9.8 (GND), U10.7 (VEE), U10.8 (GND), U11.7 (VEE), U11.8 (GND); also elsewhere on the board

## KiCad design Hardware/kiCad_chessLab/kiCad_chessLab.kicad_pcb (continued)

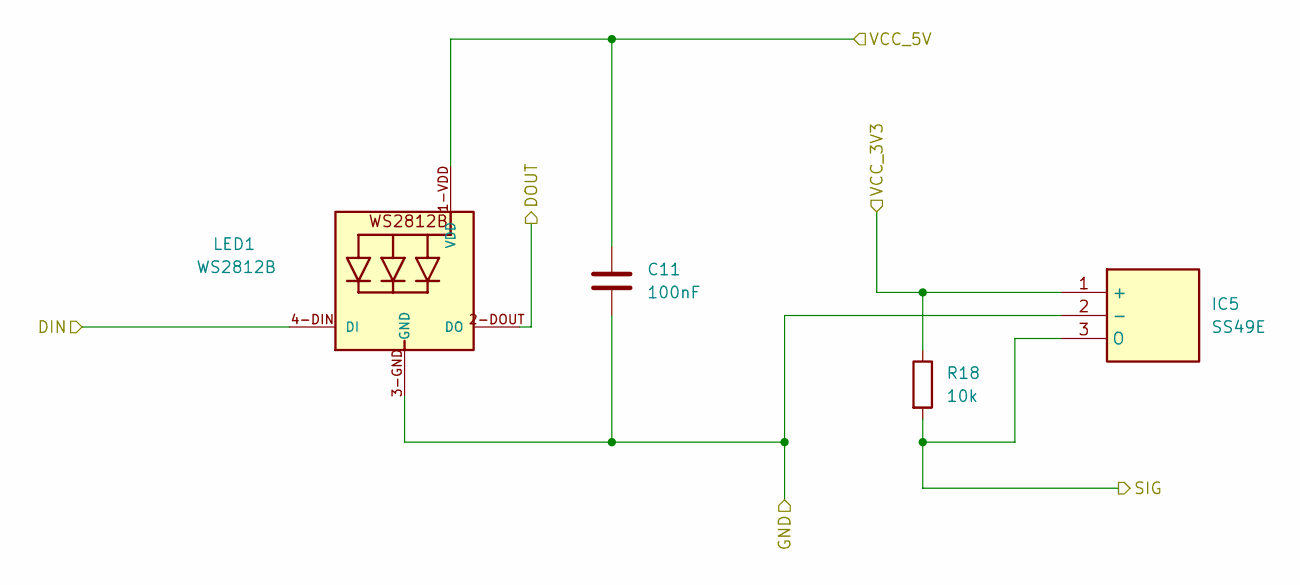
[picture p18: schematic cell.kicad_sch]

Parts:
C11: 100nF; C_0603_1608Metric_Pad1.08x0.95mm_HandSolder
IC5: SS49E; TO130P160X410X300-3P; Mouser Part Number 785-SS49E
LED1: WS2812B
R18: 10k; R_0603_1608Metric_Pad0.98x0.95mm_HandSolder

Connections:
+3V3: IC5.1 (+), R18.1; also elsewhere on the board
+5V: C11.1, LED1.1-VDD (VDD); also elsewhere on the board
/Main Board/Row_A/cell_B1/DOUT: LED1.4-DIN (DI); also elsewhere on the board
/Main Board/Row_A/cell_B2/DOUT: LED1.2-DOUT (DO); also elsewhere on the board
/Main Board/Row_A/cell_B2/SIG: IC5.3 (O), R18.2; also elsewhere on the board
GND: C11.2, IC5.2 (-), LED1.3-GND (GND); also elsewhere on the board

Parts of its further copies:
C13, C14, C15, C16, C17, C18, C19, C21, C22, C23, C24, C25, C26, C27, C28, C30, C31, C32, C33, C34, C35, C36, C37, C39, C40, C41, C42, C43, C44, C45, C46, C48, C49, C50, C51, C52, C53, C54, C55, C57, C58, C59, C60, C61, C62, C63, C64, C66, C67, C68, C69, C70, C71, C72, C73, C75, C76, C77, C78, C79, C80, C81, C82: 100nF; C_0603_1608Metric_Pad1.08x0.95mm_HandSolder
IC6, IC7, IC8, IC9, IC10, IC11, IC12, IC13, IC14, IC15, IC16, IC17, IC18, IC19, IC20, IC21, IC22, IC23, IC24, IC25, IC26, IC27, IC28, IC29, IC30, IC31, IC32, IC33, IC34, IC35, IC36, IC37, IC38, IC39, IC40, IC41, IC42, IC43, IC44, IC45, IC46, IC47, IC48, IC49, IC50, IC51, IC52, IC53, IC54, IC55, IC56, IC57, IC58, IC59, IC60, IC61, IC62, IC63, IC64, IC65, IC66, IC67, IC68: SS49E; TO130P160X410X300-3P; Mouser Part Number 785-SS49E
LED2, LED3, LED4, LED5, LED6, LED7, LED8, LED9, LED10, LED11, LED12, LED13, LED14, LED15, LED16, LED17, LED18, LED19, LED20, LED21, LED22, LED23, LED24, LED25, LED26, LED27, LED28, LED29, LED30, LED31, LED32, LED33, LED34, LED35, LED36, LED37, LED38, LED39, LED40, LED41, LED42, LED43, LED44, LED45, LED46, LED47, LED48, LED49, LED50, LED51, LED52, LED53, LED54, LED55, LED56, LED57, LED58, LED59, LED60, LED61, LED62, LED63, LED64: WS2812B
R19, R20, R21, R22, R23, R24, R25, R26, R27, R28, R29, R30, R31, R32, R33, R34, R35, R36, R37, R38, R39, R40, R41, R42, R43, R44, R45, R46, R47, R48, R49, R50, R51, R52, R53, R54, R55, R56, R57, R58, R59, R60, R61, R62, R63, R64, R65, R66, R67, R68, R69, R70, R71, R72, R73, R74, R75, R76, R77, R78, R79, R80, R81: 10k; R_0603_1608Metric_Pad0.98x0.95mm_HandSolder

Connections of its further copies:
+3V3: IC6.1 (+), IC7.1 (+), IC8.1 (+), IC9.1 (+), IC10.1 (+), IC11.1 (+), IC12.1 (+), IC13.1 (+), IC14.1 (+), IC15.1 (+), IC16.1 (+), IC17.1 (+), IC18.1 (+), IC19.1 (+), IC20.1 (+), IC21.1 (+), IC22.1 (+), IC23.1 (+), IC24.1 (+), IC25.1 (+), IC26.1 (+), IC27.1 (+), IC28.1 (+), IC29.1 (+), IC30.1 (+), IC31.1 (+), IC32.1 (+), IC33.1 (+), IC34.1 (+), IC35.1 (+), IC36.1 (+), IC37.1 (+), IC38.1 (+), IC39.1 (+), IC40.1 (+), IC41.1 (+), IC42.1 (+), IC43.1 (+), IC44.1 (+), IC45.1 (+), IC46.1 (+), IC47.1 (+), IC48.1 (+), IC49.1 (+), IC50.1 (+), IC51.1 (+), IC52.1 (+), IC53.1 (+), IC54.1 (+), IC55.1 (+), IC56.1 (+), IC57.1 (+), IC58.1 (+), IC59.1 (+), IC60.1 (+), IC61.1 (+), IC62.1 (+), IC63.1 (+), IC64.1 (+), IC65.1 (+), IC66.1 (+), IC67.1 (+), IC68.1 (+), R19.1, R20.1, R21.1, R22.1, R23.1, R24.1, R25.1, R26.1, R27.1, R28.1, R29.1, R30.1, R31.1, R32.1, R33.1, R34.1, R35.1, R36.1, R37.1, R38.1, R39.1, R40.1, R41.1, R42.1, R43.1, R44.1, R45.1, R46.1, R47.1, R48.1, R49.1, R50.1, R51.1, R52.1, R53.1, R54.1, R55.1, R56.1, R57.1, R58.1, R59.1, R60.1, R61.1, R62.1, R63.1, R64.1, R65.1, R66.1, R67.1, R68.1, R69.1, R70.1, R71.1, R72.1, R73.1, R74.1, R75.1, R76.1, R77.1, R78.1, R79.1, R80.1, R81.1; also elsewhere on the board
+5V: C13.1, C14.1, C15.1, C16.1, C17.1, C18.1, C19.1, C21.1, C22.1, C23.1, C24.1, C25.1, C26.1, C27.1, C28.1, C30.1, C31.1, C32.1, C33.1, C34.1, C35.1, C36.1, C37.1, C39.1, C40.1, C41.1, C42.1, C43.1, C44.1, C45.1, C46.1, C48.1, C49.1, C50.1, C51.1, C52.1, C53.1, C54.1, C55.1, C57.1, C58.1, C59.1, C60.1, C61.1, C62.1, C63.1, C64.1, C66.1, C67.1, C68.1, C69.1, C70.1, C71.1, C72.1, C73.1, C75.1, C76.1, C77.1, C78.1, C79.1, C80.1, C81.1, C82.1, LED2.1-VDD (VDD), LED3.1-VDD (VDD), LED4.1-VDD (VDD), LED5.1-VDD (VDD), LED6.1-VDD (VDD), LED7.1-VDD (VDD), LED8.1-VDD (VDD), LED9.1-VDD (VDD), LED10.1-VDD (VDD), LED11.1-VDD (VDD), LED12.1-VDD (VDD), LED13.1-VDD (VDD), LED14.1-VDD (VDD), LED15.1-VDD (VDD), LED16.1-VDD (VDD), LED17.1-VDD (VDD), LED18.1-VDD (VDD), LED19.1-VDD (VDD), LED20.1-VDD (VDD), LED21.1-VDD (VDD), LED22.1-VDD (VDD), LED23.1-VDD (VDD), LED24.1-VDD (VDD), LED25.1-VDD (VDD), LED26.1-VDD (VDD), LED27.1-VDD (VDD), LED28.1-VDD (VDD), LED29.1-VDD (VDD), LED30.1-VDD (VDD), LED31.1-VDD (VDD), LED32.1-VDD (VDD), LED33.1-VDD (VDD), LED34.1-VDD (VDD), LED35.1-VDD (VDD), LED36.1-VDD (VDD), LED37.1-VDD (VDD), LED38.1-VDD (VDD), LED39.1-VDD (VDD), LED40.1-VDD (VDD), LED41.1-VDD (VDD), LED42.1-VDD (VDD), LED43.1-VDD (VDD), LED44.1-VDD (VDD), LED45.1-VDD (VDD), LED46.1-VDD (VDD), LED47.1-VDD (VDD), LED48.1-VDD (VDD), LED49.1-VDD (VDD), LED50.1-VDD (VDD), LED51.1-VDD (VDD), LED52.1-VDD (VDD), LED53.1-VDD (VDD), LED54.1-VDD (VDD), LED55.1-VDD (VDD), LED56.1-VDD (VDD), LED57.1-VDD (VDD), LED58.1-VDD (VDD), LED59.1-VDD (VDD), LED60.1-VDD (VDD), LED61.1-VDD (VDD), LED62.1-VDD (VDD), LED63.1-VDD (VDD), LED64.1-VDD (VDD); also elsewhere on the board
/Main Board/Row_A/DIN: LED2.4-DIN (DI); also elsewhere on the board
/Main Board/Row_A/DOUT: LED8.2-DOUT (DO), LED14.4-DIN (DI)
/Main Board/Row_A/cell_B1/DOUT: LED2.2-DOUT (DO); also elsewhere on the board
/Main Board/Row_A/cell_B1/SIG: IC6.3 (O), R19.2; also elsewhere on the board
/Main Board/Row_A/cell_B2/DOUT: LED3.4-DIN (DI); also elsewhere on the board
/Main Board/Row_A/cell_B3/DOUT: LED3.2-DOUT (DO), LED4.4-DIN (DI)
/Main Board/Row_A/cell_B3/SIG: IC7.3 (O), R20.2; also elsewhere on the board
/Main Board/Row_A/cell_B4/DOUT: LED4.2-DOUT (DO), LED5.4-DIN (DI)
/Main Board/Row_A/cell_B4/SIG: IC8.3 (O), R21.2; also elsewhere on the board
/Main Board/Row_A/cell_B5/DOUT: LED5.2-DOUT (DO), LED6.4-DIN (DI)
/Main Board/Row_A/cell_B5/SIG: IC9.3 (O), R22.2; also elsewhere on the board
/Main Board/Row_A/cell_B6/DOUT: LED6.2-DOUT (DO), LED7.4-DIN (DI)
/Main Board/Row_A/cell_B6/SIG: IC10.3 (O), R23.2; also elsewhere on the board
/Main Board/Row_A/cell_B7/DOUT: LED7.2-DOUT (DO), LED8.4-DIN (DI)
/Main Board/Row_A/cell_B7/SIG: IC11.3 (O), R24.2; also elsewhere on the board
/Main Board/Row_A/cell_B8/SIG: IC12.3 (O), R25.2; also elsewhere on the board
/Main Board/Row_B/DOUT: LED16.2-DOUT (DO), LED22.4-DIN (DI)
/Main Board/Row_B/cell_B1/DOUT: LED9.4-DIN (DI), LED14.2-DOUT (DO)
/Main Board/Row_B/cell_B1/SIG: IC18.3 (O), R31.2; also elsewhere on the board
/Main Board/Row_B/cell_B2/DOUT: LED9.2-DOUT (DO), LED10.4-DIN (DI)
/Main Board/Row_B/cell_B2/SIG: IC13.3 (O), R26.2; also elsewhere on the board
/Main Board/Row_B/cell_B3/DOUT: LED10.2-DOUT (DO), LED11.4-DIN (DI)
/Main Board/Row_B/cell_B3/SIG: IC14.3 (O), R27.2; also elsewhere on the board
/Main Board/Row_B/cell_B4/DOUT: LED11.2-DOUT (DO), LED15.4-DIN (DI)
/Main Board/Row_B/cell_B4/SIG: IC15.3 (O), R28.2; also elsewhere on the board
/Main Board/Row_B/cell_B5/DOUT: LED12.4-DIN (DI), LED15.2-DOUT (DO)
/Main Board/Row_B/cell_B5/SIG: IC19.3 (O), R32.2; also elsewhere on the board
/Main Board/Row_B/cell_B6/DOUT: LED12.2-DOUT (DO), LED13.4-DIN (DI)
/Main Board/Row_B/cell_B6/SIG: IC16.3 (O), R29.2; also elsewhere on the board
/Main Board/Row_B/cell_B7/DOUT: LED13.2-DOUT (DO), LED16.4-DIN (DI)
/Main Board/Row_B/cell_B7/SIG: IC17.3 (O), R30.2; also elsewhere on the board
/Main Board/Row_B/cell_B8/SIG: IC20.3 (O), R33.2; also elsewhere on the board
/Main Board/Row_C/DOUT: LED24.2-DOUT (DO), LED30.4-DIN (DI)
/Main Board/Row_C/cell_B1/DOUT: LED17.4-DIN (DI), LED22.2-DOUT (DO)
/Main Board/Row_C/cell_B1/SIG: IC26.3 (O), R39.2; also elsewhere on the board
/Main Board/Row_C/cell_B2/DOUT: LED17.2-DOUT (DO), LED18.4-DIN (DI)
/Main Board/Row_C/cell_B2/SIG: IC21.3 (O), R34.2; also elsewhere on the board
/Main Board/Row_C/cell_B3/DOUT: LED18.2-DOUT (DO), LED19.4-DIN (DI)
/Main Board/Row_C/cell_B3/SIG: IC22.3 (O), R35.2; also elsewhere on the board
/Main Board/Row_C/cell_B4/DOUT: LED19.2-DOUT (DO), LED23.4-DIN (DI)
/Main Board/Row_C/cell_B4/SIG: IC23.3 (O), R36.2; also elsewhere on the board
/Main Board/Row_C/cell_B5/DOUT: LED20.4-DIN (DI), LED23.2-DOUT (DO)
/Main Board/Row_C/cell_B5/SIG: IC27.3 (O), R40.2; also elsewhere on the board
/Main Board/Row_C/cell_B6/DOUT: LED20.2-DOUT (DO), LED21.4-DIN (DI)
/Main Board/Row_C/cell_B6/SIG: IC24.3 (O), R37.2; also elsewhere on the board
/Main Board/Row_C/cell_B7/DOUT: LED21.2-DOUT (DO), LED24.4-DIN (DI)
/Main Board/Row_C/cell_B7/SIG: IC25.3 (O), R38.2; also elsewhere on the board
/Main Board/Row_C/cell_B8/SIG: IC28.3 (O), R41.2; also elsewhere on the board
/Main Board/Row_D/DOUT: LED32.2-DOUT (DO), LED38.4-DIN (DI)
/Main Board/Row_D/cell_B1/DOUT: LED25.4-DIN (DI), LED30.2-DOUT (DO)
/Main Board/Row_D/cell_B1/SIG: IC34.3 (O), R47.2; also elsewhere on the board
/Main Board/Row_D/cell_B2/DOUT: LED25.2-DOUT (DO), LED26.4-DIN (DI)
/Main Board/Row_D/cell_B2/SIG: IC29.3 (O), R42.2; also elsewhere on the board
/Main Board/Row_D/cell_B3/DOUT: LED26.2-DOUT (DO), LED27.4-DIN (DI)
/Main Board/Row_D/cell_B3/SIG: IC30.3 (O), R43.2; also elsewhere on the board
/Main Board/Row_D/cell_B4/DOUT: LED27.2-DOUT (DO), LED31.4-DIN (DI)
/Main Board/Row_D/cell_B4/SIG: IC31.3 (O), R44.2; also elsewhere on the board
/Main Board/Row_D/cell_B5/DOUT: LED28.4-DIN (DI), LED31.2-DOUT (DO)
/Main Board/Row_D/cell_B5/SIG: IC35.3 (O), R48.2; also elsewhere on the board
/Main Board/Row_D/cell_B6/DOUT: LED28.2-DOUT (DO), LED29.4-DIN (DI)
/Main Board/Row_D/cell_B6/SIG: IC32.3 (O), R45.2; also elsewhere on the board
/Main Board/Row_D/cell_B7/DOUT: LED29.2-DOUT (DO), LED32.4-DIN (DI)
/Main Board/Row_D/cell_B7/SIG: IC33.3 (O), R46.2; also elsewhere on the board
/Main Board/Row_D/cell_B8/SIG: IC36.3 (O), R49.2; also elsewhere on the board
/Main Board/Row_E/DOUT: LED40.2-DOUT (DO), LED46.4-DIN (DI)
/Main Board/Row_E/cell_B1/DOUT: LED33.4-DIN (DI), LED38.2-DOUT (DO)
/Main Board/Row_E/cell_B1/SIG: IC42.3 (O), R55.2; also elsewhere on the board
/Main Board/Row_E/cell_B2/DOUT: LED33.2-DOUT (DO), LED34.4-DIN (DI)
/Main Board/Row_E/cell_B2/SIG: IC37.3 (O), R50.2; also elsewhere on the board
/Main Board/Row_E/cell_B3/DOUT: LED34.2-DOUT (DO), LED35.4-DIN (DI)
/Main Board/Row_E/cell_B3/SIG: IC38.3 (O), R51.2; also elsewhere on the board
/Main Board/Row_E/cell_B4/DOUT: LED35.2-DOUT (DO), LED39.4-DIN (DI)
/Main Board/Row_E/cell_B4/SIG: IC39.3 (O), R52.2; also elsewhere on the board
/Main Board/Row_E/cell_B5/DOUT: LED36.4-DIN (DI), LED39.2-DOUT (DO)
/Main Board/Row_E/cell_B5/SIG: IC43.3 (O), R56.2; also elsewhere on the board
/Main Board/Row_E/cell_B6/DOUT: LED36.2-DOUT (DO), LED37.4-DIN (DI)
/Main Board/Row_E/cell_B6/SIG: IC40.3 (O), R53.2; also elsewhere on the board
/Main Board/Row_E/cell_B7/DOUT: LED37.2-DOUT (DO), LED40.4-DIN (DI)
/Main Board/Row_E/cell_B7/SIG: IC41.3 (O), R54.2; also elsewhere on the board
/Main Board/Row_E/cell_B8/SIG: IC44.3 (O), R57.2; also elsewhere on the board
/Main Board/Row_F/DOUT: LED48.2-DOUT (DO), LED54.4-DIN (DI)
/Main Board/Row_F/cell_B1/DOUT: LED41.4-DIN (DI), LED46.2-DOUT (DO)
/Main Board/Row_F/cell_B1/SIG: IC50.3 (O), R63.2; also elsewhere on the board
/Main Board/Row_F/cell_B2/DOUT: LED41.2-DOUT (DO), LED42.4-DIN (DI)
/Main Board/Row_F/cell_B2/SIG: IC45.3 (O), R58.2; also elsewhere on the board
/Main Board/Row_F/cell_B3/DOUT: LED42.2-DOUT (DO), LED43.4-DIN (DI)
/Main Board/Row_F/cell_B3/SIG: IC46.3 (O), R59.2; also elsewhere on the board
/Main Board/Row_F/cell_B4/DOUT: LED43.2-DOUT (DO), LED47.4-DIN (DI)
/Main Board/Row_F/cell_B4/SIG: IC47.3 (O), R60.2; also elsewhere on the board
/Main Board/Row_F/cell_B5/DOUT: LED44.4-DIN (DI), LED47.2-DOUT (DO)
/Main Board/Row_F/cell_B5/SIG: IC51.3 (O), R64.2; also elsewhere on the board
/Main Board/Row_F/cell_B6/DOUT: LED44.2-DOUT (DO), LED45.4-DIN (DI)
/Main Board/Row_F/cell_B6/SIG: IC48.3 (O), R61.2; also elsewhere on the board
/Main Board/Row_F/cell_B7/DOUT: LED45.2-DOUT (DO), LED48.4-DIN (DI)
/Main Board/Row_F/cell_B7/SIG: IC49.3 (O), R62.2; also elsewhere on the board
/Main Board/Row_F/cell_B8/SIG: IC52.3 (O), R65.2; also elsewhere on the board
/Main Board/Row_G/DOUT: LED56.2-DOUT (DO), LED62.4-DIN (DI)
/Main Board/Row_G/cell_B1/DOUT: LED49.4-DIN (DI), LED54.2-DOUT (DO)
/Main Board/Row_G/cell_B1/SIG: IC58.3 (O), R71.2; also elsewhere on the board
/Main Board/Row_G/cell_B2/DOUT: LED49.2-DOUT (DO), LED50.4-DIN (DI)
/Main Board/Row_G/cell_B2/SIG: IC53.3 (O), R66.2; also elsewhere on the board
/Main Board/Row_G/cell_B3/DOUT: LED50.2-DOUT (DO), LED51.4-DIN (DI)
/Main Board/Row_G/cell_B3/SIG: IC54.3 (O), R67.2; also elsewhere on the board
/Main Board/Row_G/cell_B4/DOUT: LED51.2-DOUT (DO), LED55.4-DIN (DI)
/Main Board/Row_G/cell_B4/SIG: IC55.3 (O), R68.2; also elsewhere on the board
/Main Board/Row_G/cell_B5/DOUT: LED52.4-DIN (DI), LED55.2-DOUT (DO)
/Main Board/Row_G/cell_B5/SIG: IC59.3 (O), R72.2; also elsewhere on the board
/Main Board/Row_G/cell_B6/DOUT: LED52.2-DOUT (DO), LED53.4-DIN (DI)
/Main Board/Row_G/cell_B6/SIG: IC56.3 (O), R69.2; also elsewhere on the board
/Main Board/Row_G/cell_B7/DOUT: LED53.2-DOUT (DO), LED56.4-DIN (DI)
/Main Board/Row_G/cell_B7/SIG: IC57.3 (O), R70.2; also elsewhere on the board
/Main Board/Row_G/cell_B8/SIG: IC60.3 (O), R73.2; also elsewhere on the board
/Main Board/Row_H/DOUT: LED64.2-DOUT (DO)
/Main Board/Row_H/cell_B1/DOUT: LED57.4-DIN (DI), LED62.2-DOUT (DO)
/Main Board/Row_H/cell_B1/SIG: IC66.3 (O), R79.2; also elsewhere on the board
/Main Board/Row_H/cell_B2/DOUT: LED57.2-DOUT (DO), LED58.4-DIN (DI)
/Main Board/Row_H/cell_B2/SIG: IC61.3 (O), R74.2; also elsewhere on the board
/Main Board/Row_H/cell_B3/DOUT: LED58.2-DOUT (DO), LED59.4-DIN (DI)
/Main Board/Row_H/cell_B3/SIG: IC62.3 (O), R75.2; also elsewhere on the board
/Main Board/Row_H/cell_B4/DOUT: LED59.2-DOUT (DO), LED63.4-DIN (DI)
/Main Board/Row_H/cell_B4/SIG: IC63.3 (O), R76.2; also elsewhere on the board
/Main Board/Row_H/cell_B5/DOUT: LED60.4-DIN (DI), LED63.2-DOUT (DO)
/Main Board/Row_H/cell_B5/SIG: IC67.3 (O), R80.2; also elsewhere on the board
/Main Board/Row_H/cell_B6/DOUT: LED60.2-DOUT (DO), LED61.4-DIN (DI)
/Main Board/Row_H/cell_B6/SIG: IC64.3 (O), R77.2; also elsewhere on the board
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

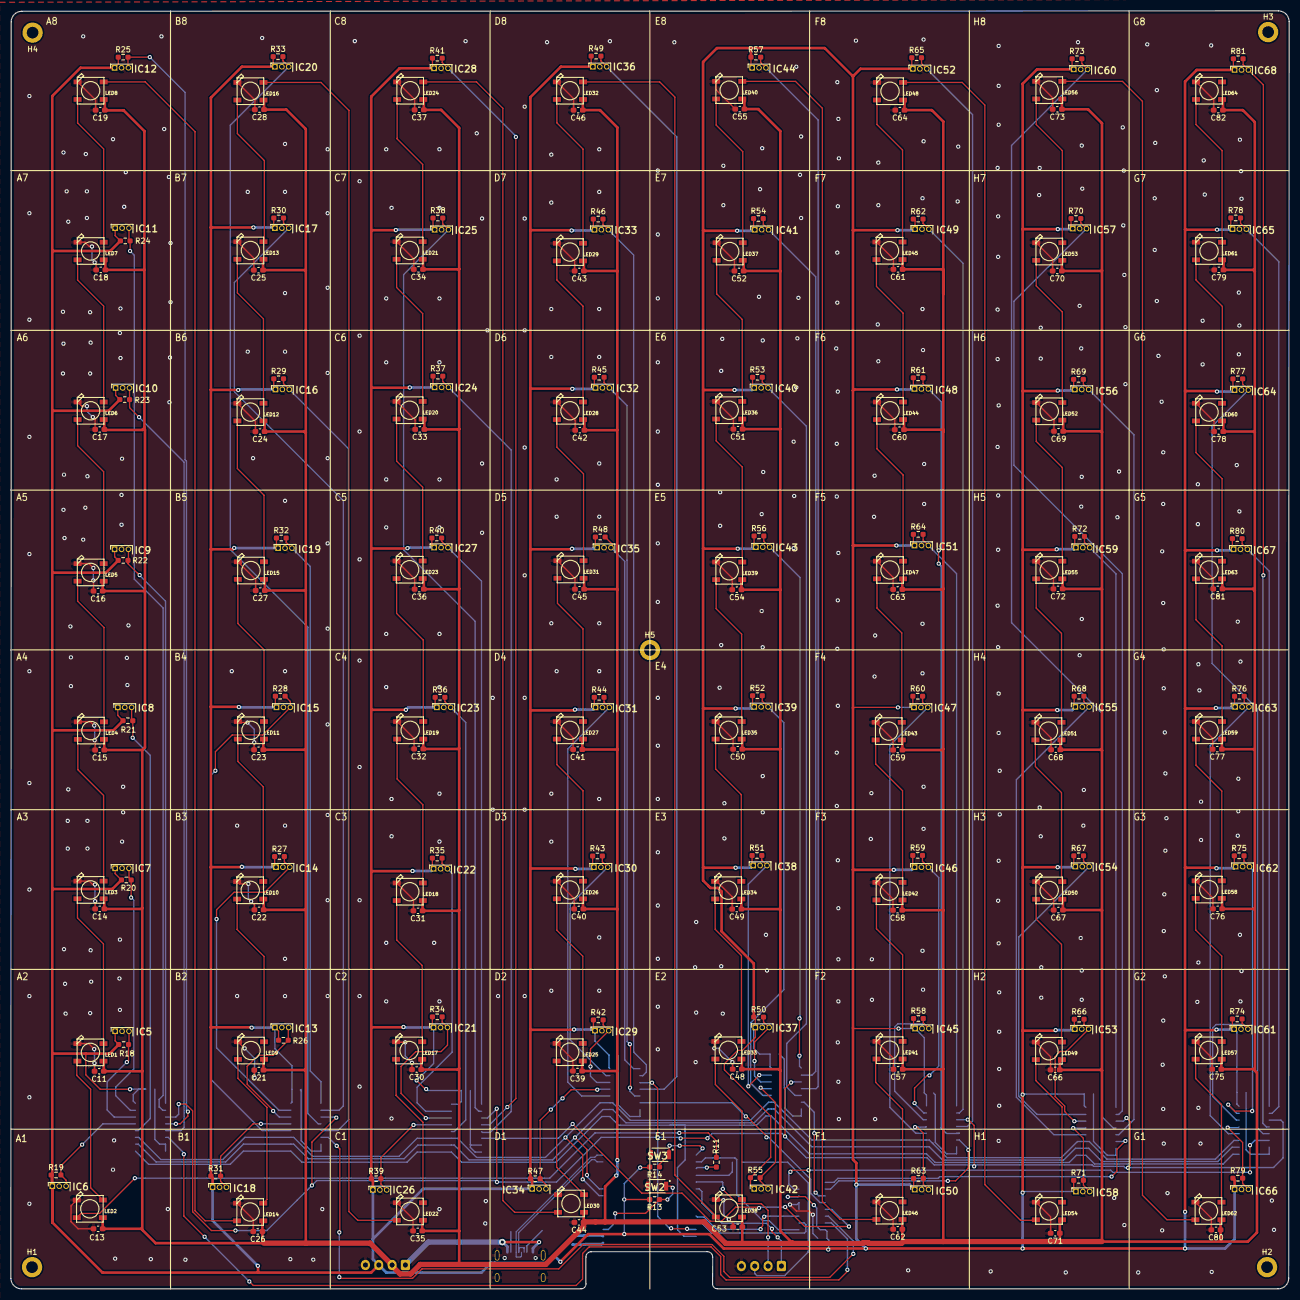
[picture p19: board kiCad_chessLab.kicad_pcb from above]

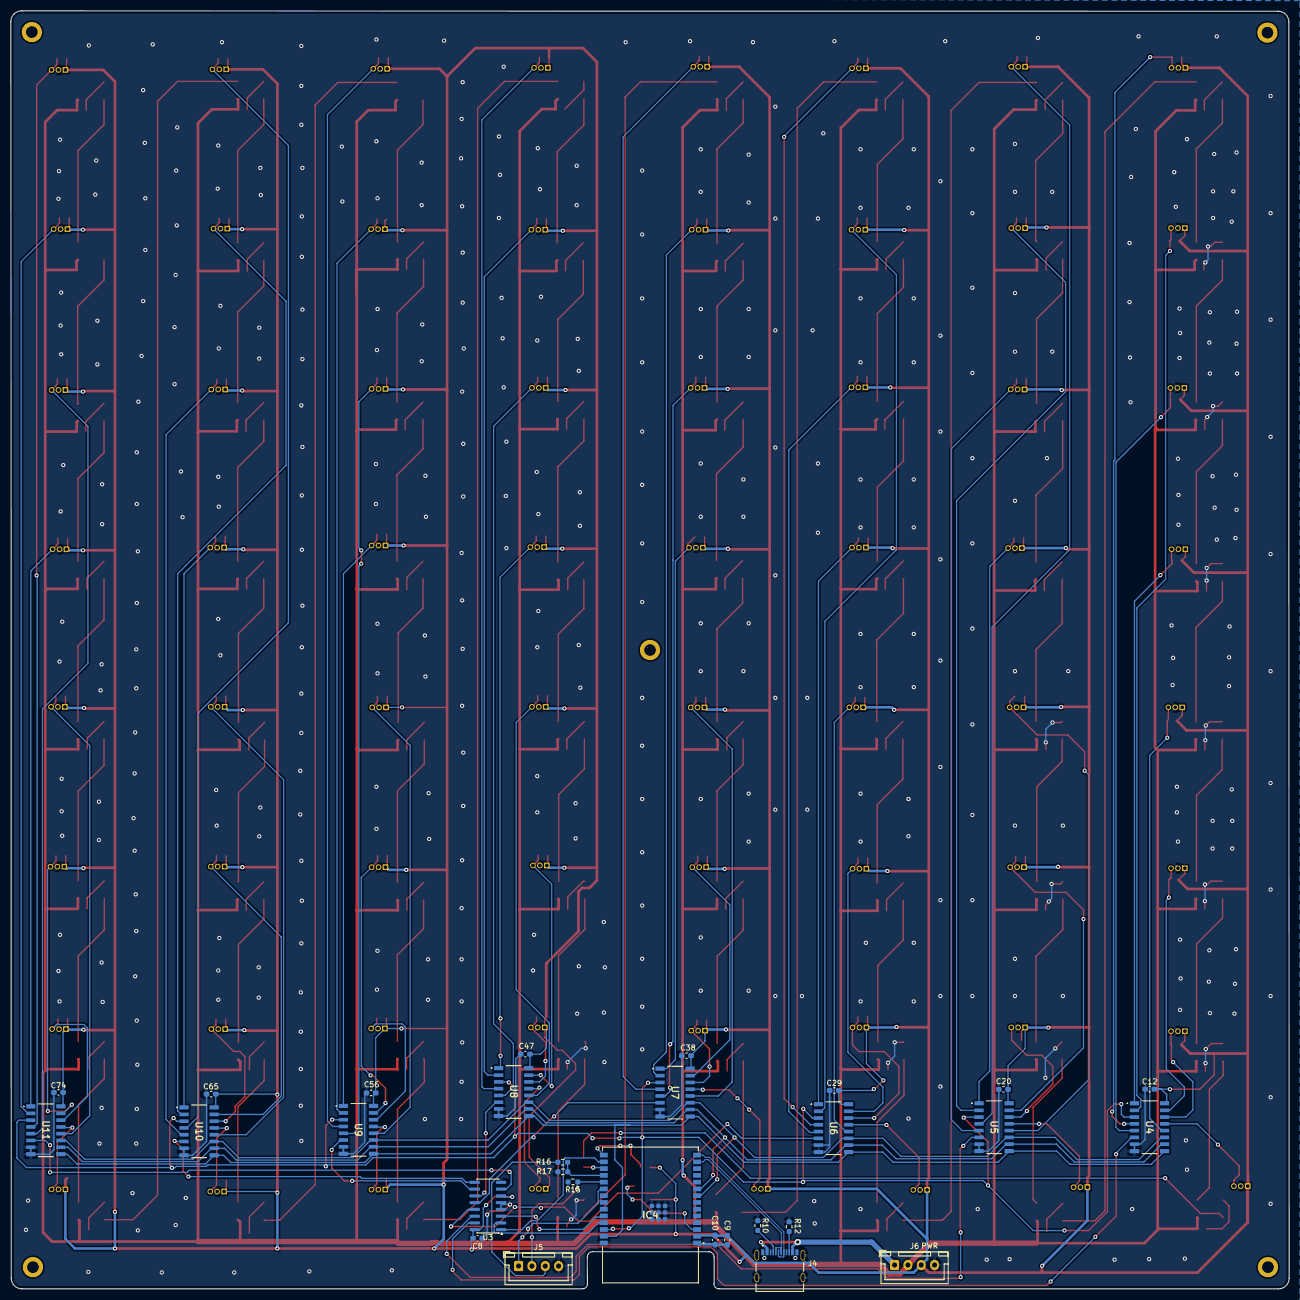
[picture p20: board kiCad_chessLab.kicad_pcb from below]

Board: 2 copper layers, 240.0 x 239.9 mm, 295 parts (29 on the bottom side), 158 nets.

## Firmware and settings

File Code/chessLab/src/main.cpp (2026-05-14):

#include <Arduino.h>
#include "board_config.h"
#include "logger.h"
#include "hal_sensors.h"
#include "hall_sensor.h"
#include "led_matrix.h"
#include "chess_game.h"
#include "web_interface.h"
#include "ota.h"

void setup() {
    Serial.begin(115200);
    Serial.setTimeout(30000);
    sensors_init();
    leds_init();
    hall_calibrate();
    game_init();
    ota_init();       // WiFi doit être up avant logger_init()
    logger_init();
    web_init();
    LOG("=== ChessLab — INIT sequence OK ===\n");
}

void loop() {
    static int dev[BOARD_SIZE][BOARD_SIZE];
    static int start_ok_frames = 0;

    logger_update();

    // WiFi d'abord : vider la file d'envoi/réception avant de toucher l'ADC
    web_update();
    ota_update();

    hall_scan(dev);  // ADC après le flush WiFi → moins d'interférences

    if (game_get_phase() == GAME_SETUP) {
        leds_animate_setup(dev);

        if (game_check_start_position(dev)) {
            if (++start_ok_frames >= 5) {
                game_set_phase(GAME_PLAYING);
                LOG("=== Position de départ validée — jeu commence ===\n");
                leds_flash_green();
                start_ok_frames = 0;
            }
        } else {
            start_ok_frames = 0;
        }
    } else {
        leds_update(dev);
    }

    game_update(dev);
    web_broadcast_state(dev);  // mis en file, sera transmis au prochain web_update()
}

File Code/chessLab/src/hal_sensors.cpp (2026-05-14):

#include <Arduino.h>
#include "board_config.h"
#include "hal_sensors.h"

// Écrit une valeur 3 bits sur trois broches de sortie (bit0 → p0, bit1 → p1, bit2 → p2)
static void write_addr(int p0, int p1, int p2, int val) {
    digitalWrite(p0,  val       & 1);
    digitalWrite(p1, (val >> 1) & 1);
    digitalWrite(p2, (val >> 2) & 1);
}

void sensors_init() {
    pinMode(HALL_DOUT, INPUT);
    for (int p : {DEC_A0, DEC_A1, DEC_A2, SEL_S0, SEL_S1, SEL_S2})
        pinMode(p, OUTPUT);
}

void sensors_select_row(int row) {
    digitalWrite(DEC_A0, (row >> 0) & 1);
    digitalWrite(DEC_A1, (row >> 1) & 1);
    digitalWrite(DEC_A2, (row >> 2) & 1);
}

void sensors_select_col(int col) {
    digitalWrite(SEL_S2, (col >> 2) & 1);
    digitalWrite(SEL_S1, (col >> 1) & 1);
    digitalWrite(SEL_S0, (col >> 0) & 1);
}

int sensors_read_raw(int row, int col) {
    sensors_select_col(col);
    sensors_select_row(row);
    delayMicroseconds(2000);  // stabilisation mux

    // 30 échantillons espacés de 60 µs : les pics WiFi n'affectent que quelques samples
    // Moyenne tronquée (jeter 6 extremes) → robuste aux rafales WiFi
    const int N = 30, TRIM = 6;
    int s[N];
    for (int i = 0; i < N; i++) {
        s[i] = analogRead(HALL_DOUT);
        delayMicroseconds(60);
    }

    for (int i = 1; i < N; i++) {
        int key = s[i], j = i - 1;
        while (j >= 0 && s[j] > key) { s[j+1] = s[j]; j--; }
        s[j+1] = key;
    }

    int sum = 0;
    for (int i = TRIM; i < N - TRIM; i++) sum += s[i];
    return sum / (N - 2 * TRIM);
}

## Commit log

2026-03-03 Inclusion of KiCad Project
    [kiCad_chessLab.kicad_pcb, kiCad_chessLab.kicad_sch]
2026-03-03 Include Lib and readme changes
    [kiCad_chessLab.kicad_sch]
2026-03-03 Kicad config
2026-03-04 KiCad Libs Config
2026-03-04 Creation des Cellules et Fonctions de Multiplexage
    Organisation du projet KiCad en SousPages
    Creation des Fonctions Cell: Gestion individuelle de une case
    Row: Multiplexage de 8 cell
    Main Board:
    Liaisons avec ESP32C6
    [cell.kicad_sch, main_board.kicad_sch, row.kicad_sch]
2026-03-04 KiCad Bug Fix
    [cell.kicad_sch, main_board.kicad_sch]
2026-03-05 Main Board update
    [cell.kicad_sch, main_board.kicad_sch, power_board.kicad_sch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]
2026-03-06 Finished Schematics
2026-03-06 Complete Schematics
    [cell.kicad_sch, main_board.kicad_sch, power_board.kicad_sch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]
2026-03-06 Fixing some footprints that were missmatched and issues with components import to pcb
2026-03-07 PCB SetUp
    [kiCad_chessLab.kicad_pcb, main_board.kicad_sch, power_board.kicad_sch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]
2026-03-07 Hall effect Replaced and 3d files uploaded
    [74HC4051D,653.STEP, DW01A--3DModel-STEP-56544.STEP, ESP32-C6-WROOM-1-N8.stp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]
2026-03-08 Pcb Continued
    [kiCad_chessLab.kicad_pcb]
2026-03-09 Update PCB
    [kiCad_chessLab.kicad_pcb]
2026-03-27 maj pcb
    [kiCad_chessLab.kicad_pcb]
2026-03-28 Clean Up Power Board
    [kiCad_chessLab.kicad_pcb, kiCad_chessLab.kicad_sch, main_board.kicad_sch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]
2026-03-28 Via stitch
    [kiCad_chessLab.kicad_pcb]
2026-03-28 Final PCB chess
    [kiCad_chessLab.kicad_pcb]
2026-03-29 power pcb
    [powerBoard.kicad_pcb, powerBoard.kicad_sch]
2026-04-01 PowerBoard pcb FRev2
    [powerBoard.kicad_pcb]
2026-04-01 Power Board FREV2
    [powerBoard.kicad_pcb, powerBoard.kicad_sch]
2026-05-05 Rearrange + Code init
    [74HC4051D,653.STEP, DW01A--3DModel-STEP-56544.STEP, ESP32-C6-WROOM-1-N8.stp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]
2026-05-05 Half way
    [kiCad_chessLab.kicad_pcb]
2026-05-07 hall test
2026-05-13 Hall Works
2026-05-13 Hall Fix
2026-05-13 FIX telnet and OPA
    [hal_sensors.cpp, ota.cpp]
2026-06-04 refactor: relier le bouton poussoir à l'esp32
    [74HC4051D,653.STEP, B4B-XH-A_LF__SN_.step, DW01A--3DModel-STEP-56544.STEP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]
2026-06-04 Diodes size fix
    [powerBoard.kicad_pcb]
2026-06-05 ajout des vias et le nom sur la carte
    [powerBoard.kicad_pcb, powerBoard.kicad_sch]
2026-06-08 AJOUT DES NOMS SUR LES CONNECTEURS EXTERIEURS
    [powerBoard.kicad_pcb, powerBoard.kicad_sch]
2026-06-08 Ajout des via et les noms sur la carte
2026-06-08 ajout de via et les noms sur la carte
2026-07-01 Gitugnore update
    [bom.csv, designators.csv, positions.csv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]
2026-07-10 Change sensor model from A3144 to SS49E
    Updated sensor information and corrected model names in the README.
